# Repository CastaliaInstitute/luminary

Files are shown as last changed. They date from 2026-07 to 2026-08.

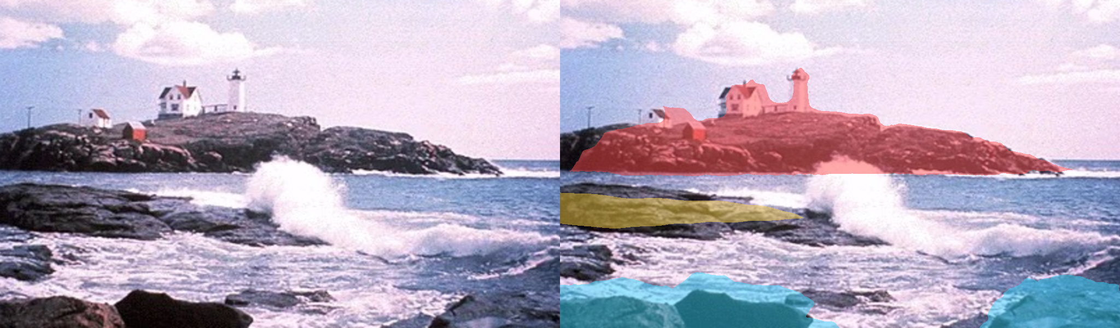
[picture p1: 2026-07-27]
renders/nubble-source-validation.png

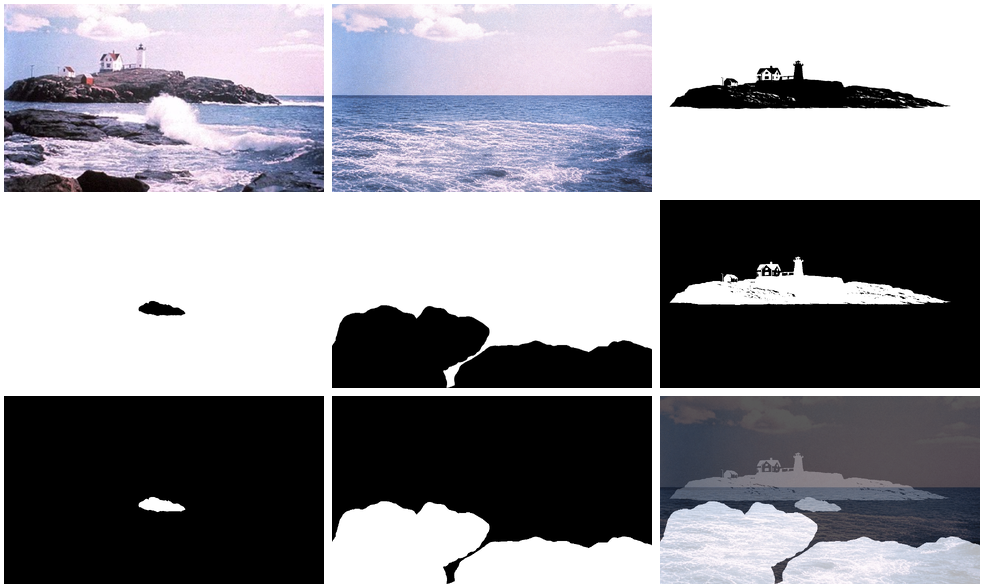
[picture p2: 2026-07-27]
renders/nubble-debug-montage.png

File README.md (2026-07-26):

# Luminary

CastaliaInstitute project repository for **Luminary**, an illuminated coastal shadow box.

## Status

Production-candidate STL package and STL-based render are ready for physical P4 fit testing.
This repository is the source of truth for the Luminary project.

## Repository layout

```text
.
├── README.md
├── blender/        # Blender scene-generation script
├── cad/            # Parametric OpenSCAD model
├── docs/          # Product, design, and technical notes
├── renders/        # Concept render and fit-check STLs
└── src/           # Implementation source
```

## Getting started

The project page is published at [luminary.castalia.institute](https://luminary.castalia.institute).

Open `cad/lightbox.scad` in OpenSCAD to inspect or export the current parametric model.
The latest production-candidate render is `renders/nubble-concept.png`; the editable Blender
scene is `renders/nubble-concept.blend`. The release print set and physical assembly notes are
in [`docs/production-build.md`](docs/production-build.md).

For new scenes, follow the [landscape photo workflow](docs/landscape-photo-workflow.md).
It defines the AI background-fill, source-faithful silhouette, SVG, print-validation, and
off-axis display-alignment process.

The first three-layer example is documented in the [Nubble source run](docs/nubble-source-run.md).
Its exported meshes are in `renders/stl/nubble-*.stl`, with the corresponding actual-STL
Blender render at `renders/nubble-concept.png`.

## Project principles

- Keep the project understandable and easy to pick up.
- Record important product and technical decisions in `docs/`.
- Prefer small, reviewable changes with clear commit messages.

## Maintainer

CastaliaInstitute

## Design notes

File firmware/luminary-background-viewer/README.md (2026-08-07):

# Luminary P4 runtime viewer

Production ESP-IDF firmware for the **Waveshare ESP32-P4-WIFI6-Touch-LCD-7B** only. It drives the 1024×600 EK79007 MIPI-DSI panel in RGB888 and renders a continuously evolving Nubble sea and sky behind the printed bas-relief.

## Registration contract

- Canvas: exactly 1024×600
- Camera bearing: 90°
- Horizon: immutable row **291**
- The packed water mask is false above row 291.
- Cloud opacity is feathered to zero before the horizon and cannot touch the sea.
- Foam can exist only in registered water pixels near the signed shore-distance field.
- Land is physical printed relief; the runtime never invents or moves it.

## Runtime model

The base image is decoded once by the P4 JPEG engine. At 10 fps, firmware then:

1. Projects NDBC's measured swell and wind-wave partitions onto a horizontal world-space sea plane.
2. Animates surface normals and reflections without translating source pixels, then steepens incoming crests into foam only inside the registered shoreline-distance field.
3. Composites GOES high, mid, and low cloud shells, each rotated continuously by its own GOES Derived Motion Wind vector and measured cloud height.
4. Uses the live Nubble camera as the final authority for visible sky color and cloud fraction. A confident clear camera observation sets shell opacity to zero even if an older satellite field contains cloud.
5. Synchronizes UTC directly with SNTP and recalculates York's actual solar altitude and azimuth on the P4 every 30 seconds. Golden hour begins continuously at +10°, peaks at the horizon crossing, and fades through twilight. Sunset remains physically behind the east-facing camera while warming the correctly oriented horizon, clouds, and water reflection. A moon is drawn only when measured altitude/azimuth places it inside the camera view, before cloud compositing so clouds can occlude it.
6. Projects the ESA Hipparcos naked-eye catalogue through the same locked camera. ICRS positions receive catalogue proper motion and date precession before conversion to York-local altitude/azimuth. Solar altitude controls limiting magnitude, and the three measured cloud shells attenuate stars rather than allowing them to shine through cloud.

The compiled asset is an offline-safe fallback. In production the P4 polls a versioned HTTPS manifest every five minutes, downloads changed state, three compact 256×96 luminance/alpha cloud-shell atlases, and a compact 512×300 RGB ocean phase atlas containing up to three independently measured wave components. It verifies every size and CRC32, then activates the complete bundle atomically. It keeps rendering the previous validated bundle through network or upstream failures.

For visual QA on the local network, `GET /runtime/screenshot.ppm` returns a lossless capture of the exact BGR888 scanout framebuffer converted to RGB PPM. This captures only display content; the physical Nubble bas-relief remains intentionally absent.

The default endpoint is the repository's force-refreshed `runtime-live` branch on `raw.githubusercontent.com`, which has a valid public TLS chain. `luminary.castalia.institute` mirrors the project site but is not trusted as a firmware endpoint until its custom-domain certificate is valid.

## Autonomous refresh

The P4 initiates refreshes; it does not require an inbound connection or a Mac on the local network. GitHub Actions preprocesses the heavy NOAA GOES NetCDF products and Nubble live-camera observation into the compact bundle the P4 can consume. The workflow replaces the history-free `runtime-live` branch every five minutes, avoiding unbounded binary Git history.

The scene swap is all-or-nothing:

1. Fetch `manifest.json` over verified HTTPS.
2. Ignore an unchanged `bundle_id`.
3. Download all cache-busted binary assets into temporary PSRAM.
4. Validate byte counts, CRC32 values, state JSON, and immutable horizon row 291.
5. Acquire the renderer lock once and activate the complete bundle.

The cloud and sea fields continue moving from monotonic time while a refresh is downloaded.

## Optional microSD asset cache

Insert a FAT-formatted microSD card in the onboard TF socket to retain the last validated runtime scene across power loss and offline starts. The cache is optional: firmware always boots from its embedded scene when the card is absent, unreadable, or corrupt, and then refreshes over HTTPS when Wi-Fi becomes available.

The P4 stores two alternating files as `/luminary/RUN_A.BIN` and `/luminary/RUN_B.BIN`. Each file contains the state JSON, all three cloud atlases, and the ocean phase field with a sequence number and CRC32. The validity marker is written only after the complete file has been flushed, so a power interruption during an update leaves the other slot intact. At boot, firmware validates both slots and activates the newest complete bundle before connecting to the network. The short filenames remain compatible with builds that omit FAT long-filename support.

The TF socket runs in its board-supported SPI mode on MISO 39, CS 42, CLK 43, and MOSI 44. Firmware enables the board's required on-chip LDO channel 4 before card initialization. This deliberately isolates removable storage from the ESP-C6 Wi-Fi coprocessor, which uses the P4's separate SDIO slot. The fixed Hipparcos catalogue and boot-safe scene remain embedded in flash.

## Maintenance push API

The P4 still listens on port 80 after Wi-Fi connects for development and recovery:

- `POST /runtime/cloud/high`
- `POST /runtime/cloud/mid`
- `POST /runtime/cloud/low`
- `POST /runtime/ocean-phase`
- `POST /runtime/state`

Each cloud payload is exactly 49,152 bytes and the three-component ocean phase payload is exactly 460,800 bytes. The host uploads all binary fields first and the JSON state last; the state request is the visible commit point. The device rejects any state whose horizon is not row 291.

From the repository root:

```sh
python3 scripts/update-york-runtime.py --deploy
```

That command fetches York weather, NDBC 44098 standard and spectral-partition observations, and York tide predictions; observes the live Nubble camera; downloads GOES C13/ACHA clouds and C14 motion winds; builds and validates the cloud and sea fields; packs the runtime assets; then atomically deploys them to the P4. Use `--reuse-dmw` only for offline/repeat testing.

## Optional local builder

The macOS LaunchAgent is an optional development fallback, not part of the production runtime path. It can build and push a scene directly while testing upstream changes. Production data is generated by `.github/workflows/runtime.yml`, and the P4 fetches it itself.

Service label: `institute.castalia.luminary-realtime`

```sh
launchctl print gui/$(id -u)/institute.castalia.luminary-realtime
tail -f ~/Library/Logs/Luminary/realtime.log
```

The host Mac needs to be awake and connected to the P4's local network only when using this optional direct-push path.

Validate and preview without deploying:

```sh
python3 scripts/update-york-runtime.py --reuse-dmw
python3 scripts/preview-p4-runtime.py \
  --state firmware/luminary-background-viewer/assets/v2/nubble-runtime-scene-v1.json \
  --assets firmware/luminary-background-viewer/assets/runtime \
  --output tmp/york-live/runtime-production-preview
python3 scripts/validate-production-runtime.py \
  --state firmware/luminary-background-viewer/assets/v2/nubble-runtime-scene-v1.json \
  --assets firmware/luminary-background-viewer/assets/runtime \
  --preview tmp/york-live/runtime-production-preview
```

## Build and flash

Wi-Fi credentials remain local build inputs in ignored `sdkconfig`; do not put them in source or logs.

```sh
. /Users/danielmcshan/esp/esp-idf-v5.5.1/export.sh
idf.py -B build-runtime set-target esp32p4
idf.py -B build-runtime build
idf.py -B build-runtime -p /dev/cu.wchusbserial5B901846451 flash monitor
```

Only use a serial path after positively identifying this exact P4 board. The current application is about 2.71 MB, leaving roughly 14% of the 3 MB app partition free. The renderer runs on a dedicated task whose stack lives in internal SRAM — a PSRAM or RTC-RAM stack slows every stack access enough to stretch one frame into seconds. The composed sky (clouds, solar grading, moon, stars) is cached in double-buffered PSRAM, rebuilt a few rows per frame when wind or solar state moves it, and blitted only when a framebuffer does not already carry it, so clear and cloudy scenes both hold 10 fps (~96 ms measured under full overcast). Confirm against the serial `runtime cadence` measurements after changing the renderer.

Legacy `.lumv` assets remain under `assets/v2` for comparison, but the production firmware no longer loops finite JPEG sequences.

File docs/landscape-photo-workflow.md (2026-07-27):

# Landscape photo to Luminary bas-relief workflow

The photograph is the composition authority. AI may segment or fill an image,
but it must not redesign the landform, move the horizon, or change the scale
relationship between a distant island, breaker, and foreground rocks.

Luminary's production configuration is a 7 x 5 in landscape shadow box with a
Waveshare ESP32-P4-WIFI6-Touch-LCD-7B at the rear. The physical scene field is
5.5 x 3.5 in (139.7 x 88.9 mm) behind a 5.25 x 3.25 in wood sight aperture.
It uses a 1024 x 600 working canvas. The narrow sight mat deliberately hides
the LCD edge and the cropped field margin.

## 1. Normalize the source

Create `scenes/<scene>/source.png` from the best available photograph:

- landscape orientation;
- exactly 1024 x 600 pixels;
- preserve the intended island, breaker, foreground contours, and horizon;
- do not independently crop later layer inputs.

The source coordinates are geometry. Every generated mask must retain this
same 1024 x 600 canvas and pixel registration.

## 2. Create the land-free LCD background

Use image generation with the source photograph as a reference:

> Edit this supplied landscape photograph into a photorealistic background.
> Preserve its exact horizon height, clouds, atmosphere, water direction, and
> lighting. Remove all land, buildings, shoreline, rocks, foam, and people;
> naturally fill the removed areas with continuous water. Do not move or crop
> the composition, add text, or change the photographic style.

Save the result at `scenes/<scene>/background.png`, exactly 1024 x 600. This
is the only sky and water image displayed by the P4.

## 3. Segment opaque printed layers

Make three source-registered, black-on-white PNG masks, each exactly 1024 x
600, and save them next to the source:

| Layer | File | Physical placement |
| --- | --- | --- |
| Distant island/shore | `island.png` | LCD contact plane |
| Midground peninsula including the breaking-wave rock | `breaker-source-segmentation.png` | 2.5 mm forward |
| Nearest foreground rocks | `foreground.png` | 5.0 mm forward |

The source-derived midground peninsula is intentionally separate from the
distant island and foreground. It must remain connected to its source-side
field edge; do not make its breaker tip into a floating island. Exclude water
and foam. Rocks are opaque; transparent rock areas make the display show
through and invalidate the physical scene.

Use AI only as a segmentation aid. Validate each mask by compositing it over
the original source, at identical pixel dimensions. Reject a mask if it moves
shoreline edges, flattens the bottom profile, makes the foreground too large,
or invents a landform.

White building/lighthouse inserts are optional and must remain out of the print
set until a separately segmented, source-aligned architecture mask is reviewed.
Do not improvise their scale from a generative image.

## 4. Compile and inspect registration

Run:

```sh
scripts/compile-bas-relief.sh <scene>
```

The compiler centre-crops the same 943 x 600 source region from the LCD
background and every mask, then normalizes it back to 1024 x 600 for the
5.5 x 3.5 in physical field. This shared crop is essential: independent
resize/crop steps create visible parallax errors.

Inspect `scenes/<scene>/compiled/reference-alignment.png` before exporting:

- island appears red;
- breaker appears gold;
- foreground appears cyan.

All contours must track the original photograph. This review is against the
source photo, not the generated LCD background.

## 5. Build the printable bas-relief

For Nubble, export the three opaque bases from
`cad/bas_relief_scene.scad`, then create the source-tonal companion meshes:

```sh
python3 scripts/build-rock-texture-mesh.py \
  scenes/<scene>/compiled/island-texture.png \
  renders/stl/<scene>-basrelief-island-texture.stl --base-z 1.6
```

Repeat for breaker (`--base-z 3.2`) and foreground (`--base-z 5.0`). The mesh
samples 0.2 x 0.2 mm XY detail and converts source tones into a maximum 1.35
mm printable height field. Load each texture STL with its matching base STL as
one object in the slicer; print at 0.12 mm layers.

Do not use the 2 in box depth as a 20-35 mm parallax gap. The scene is a
shallow bas-relief: the contact island is at the display, breaker 2.5 mm
forward, and foreground 5 mm forward. That depth is enough to reveal form at
a slight angle while retaining source/background registration.

## 6. Render and verify

Render only imported production STLs:

```sh
LUMINARY_SCENE=nubble /Applications/Blender.app/Contents/MacOS/Blender \
  --background --python blender/luminary_scene.py
scripts/verify-production.sh
```

The verifier rebuilds the source-alignment artifact and checks every required
STL for nonmanifold and boundary edges. Reject the scene if the product render
shows a background shift at the selected three-quarter camera angle, or if the
reference-alignment overlay disagrees with the source photograph.

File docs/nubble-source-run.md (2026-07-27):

# Nubble source run

The Nubble Lighthouse scene is represented by four separate AI-assisted visual assets.
These are the canonical references for the next silhouette revision; do not collapse them
into a generic one-piece trace.

| Layer | Asset | Use |
| --- | --- | --- |
| LCD sky and water | `assets/display-nubble-1280x720.png` | 1280 × 720 display background |
| Distant island and lighthouse | `assets/source/nubble-island-ai.jpg` | Main black island / white-building tracing reference |
| Middle breaker rock | `assets/source/nubble-breaker-rock-ai.png` | Shallow black rock under the crashing wave |
| Foreground boulders | `assets/source/nubble-foreground-rocks-ai.png` | Separate raised black foreground tracing reference |

`assets/source/nubble-background-ai.jpg` is retained as the uncropped background source.

## Layering rule

The island output intentionally contains no foreground boulders. The breaker-rock output
provides the low physical target for the wave. The foreground-rock output intentionally
contains no island, lighthouse, or sky. Keep all three as independent physical layers, held
by the hidden ring and narrow clear traces where a rock is isolated. This preserves open
water on the display between the foreground, breaker, and island.

## Printable extraction

`cad/nubble_layers.scad` turns the approved AI separations into four print-ready meshes:

- `renders/stl/nubble-magnetic-frame.stl` — hidden 6 × 4 in magnetic carrier with four 3.2 mm magnet pockets
- `renders/stl/nubble-island-layer.stl` — distant island and lighthouse mask
- `renders/stl/nubble-breaker-layer.stl` — the single middle rock where the wave breaks
- `renders/stl/nubble-foreground-layer.stl` — near boulders

The first is installed behind the wood mat; the three opaque masks stack toward the glass.
The LCD remains the fourth visual layer (sky and water), mounted at the rear of the fixed
2 in box. Artwork is registered for the straight-on viewing position; the angled view is
allowed to reveal the intended shadow-box parallax.
`renders/nubble-concept.png` is the Blender render made by importing those exact STL files.

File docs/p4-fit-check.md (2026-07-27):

# Luminary P4 physical fit check

Run this check before printing or installing the structural rear plate. It
validates the specific Waveshare ESP32-P4-WIFI6-Touch-LCD-7B board used by
Luminary; do not substitute the earlier portrait 5-inch P4 board.

## Evidence used by the CAD

The Waveshare outline drawing specifies a 164.00 x 97.00 mm board and a
164.28 x 99.17 mm LCD/bezel envelope. The rear plate's 166.0 x 101.6 mm
registration land therefore leaves 0.86 mm clearance at each long side and
1.215 mm at each short side of the bezel. The low-material fit ring uses the
same nominal corner-hole centers as the rear plate: +/-78 mm X and +/-44 mm Y,
with 6.0 x 5.2 mm horizontal M2.5 tolerance slots.

Source: [Waveshare ESP32-P4-WIFI6-Touch-LCD-7B outline drawing](https://www.waveshare.com/esp32-p4-wifi6-touch-lcd-7b.htm).

## Print

Print [luminary-7in-p4-fit-check.stl](../renders/stl/luminary-7in-p4-fit-check.stl)
flat in the intended rear-plate material at 0.20 mm layers. It is deliberately
only 1 mm thick and consumes little material. Do not scale it.

## Acceptance criteria

1. The board perimeter must sit entirely inside the 166.0 x 101.6 mm ring
   without forcing or bowing the printed plastic.
2. Each of the four board mounting holes must accept an M2.5 screw through its
   corresponding test-ring slot with at least 0.5 mm of unforced adjustment in
   both axes.
3. With all four screws finger-tightened, the LCD/bezel must lie flat and
   centered; no corner may lift more than 0.3 mm from the registration land.
4. Connect the selected right-side USB-C extension internally and route its
   external cable through both the side and bottom-center 8 mm plate exits.
   The connector and cable must not bear against the PCB, display flex, or
   screw head.
5. Confirm the selected 6 x 2 mm magnets sit below the rear plate surface and
   that their polarity attracts the intended steel-frame plates.

If any criterion fails, measure the actual board-hole coordinates from the
board center, edit the constants at the top of
`cad/luminary-7in-backplate.scad` and
`cad/luminary-7in-p4-fit-check.scad` together, then re-export both STLs.
Never enlarge a completed structural plate by drilling; that can reduce the
wall around its cable exits or magnet pockets.

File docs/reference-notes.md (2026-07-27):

# Lightbox CAD reference notes

## Source references

- `references/Living_Landscape_Shadow_Box_Design_v0.1.pdf`
- `references/Photo 1.jpg`
- `references/Photo 2.jpg`
- `references/Pasted Image 1.jpg`
- `references/Distressed White Frame.jpg`
- `assets/living-landscape-silhouette.svg`
- `assets/living-landscape-foreground.svg`
- `assets/living-landscape-structures.svg`

## Dimensions captured

| Feature | Value | Confidence |
| --- | ---: | --- |
| Nominal shadow-box exterior | 7 × 5 × 2 in (177.8 × 127.0 × 50.8 mm) | Design brief + measured depth |
| Nominal interior / silhouette panel | 6 × 4 in (152.4 × 101.6 mm) | Design brief |
| Waveshare display outer envelope | 126.90 × 70.70 mm | Product reference image |
| Display active area | 110.32 × 62.28 mm | Product reference image |
| Waveshare PCB envelope | 118.50 × 64.50 mm | Product reference image |
| Silhouette mounting frame | 4 × 6 in, 0.8 mm face, hidden under 8 mm glass rabbet | Design brief + mechanical revision |
| Inner mounting-frame edge | 2 mm tapered feather | Mechanical revision |
| Hidden rear ribs | ~2 mm deep | Design brief |
| Magnet reference | 3 × 1 mm neodymium | Design brief |
| Silhouette-to-display depth | 20 mm target | Reduces off-axis parallax while retaining shadow depth |
| Clear glass / mat opening | 114.3 × 88.9 mm (4.5 × 3.5 in) | Actual visible front aperture |
| Printed rear plate | 177.8 × 127.0 mm (5 × 7 in) | New mechanical requirement |
| Shallow rear registration land | 152.4 × 101.6 mm (4 × 6 in) | New mechanical requirement |
| USB-C cable pass-throughs | 8 mm circular default, side + bottom-center | New mechanical requirement |
| Silhouette magnet reference | 3 × 1 mm magnet in 8 × 8 × 2 mm hidden corner pod, 4 corners | Design brief + mechanical revision |
| Glass steel squares | 1/4 × 1/4 in, 4 corners | New mechanical requirement |

## Modeling assumptions

The OpenSCAD model is a fit-check starter, not a release-ready manufacturing model. The
following need physical verification before printing a final carrier or enclosure:

- actual frame inner opening, rabbet, glass thickness, and usable depth;
- display-to-frame registration and cable exit locations;
- PCB mounting-hole coordinates and connector keep-outs;
- magnet polarity, steel-square placement, and pocket tolerances;
- whether the 4 × 6 panel is centered or offset within the frame.
- exact cable diameter, grommet choice, and cable bend radius;
- exact P4 PCB hole coordinates and connector keep-outs;
- steel plate thickness, position, and spacing relative to the silhouette magnet pockets.

The 2 in outer depth is now the controlling dimension. The model uses a 20 mm
silhouette-to-screen depth, preserving roughly 30 mm for the display carrier, P4 PCB,
rear plate, and clearance. This reduces the background's apparent shift when viewed at a
slight angle. This is a fit allocation, not proof of fit; confirm the tallest P4-side
component before printing.

## Usage

Open `cad/lightbox.scad` in OpenSCAD and set `part` to `assembly`, `silhouette`, `structures`,
`glass_hardware`, `backplate`, `carrier`, `display`, or `pcb`. Render with F6, then export the selected part as STL. The geometry is
centered on the origin so it can be aligned with a future SVG-derived landscape silhouette.

## Silhouette composition

`assets/lighthouse-silhouette-source-v3.png` is the latest AI-assisted, source-preserving
tracing reference. `assets/living-landscape-photo-trace.svg` is its Potrace-derived black
relief used by the CAD: compact island, separated foreground boulders, and modest lighthouse
scale rather than the earlier abstract trace. Sky, water, and surf are intentionally omitted
so the display can provide those elements and their animation.

## Relief strategy

The silhouette is designed around a 0.2 mm nozzle: the source-traced black scene is 4 layers
(0.8 mm) and bonds to the transparent carrier. The lighthouse and cottage insert is a
separate white-print part at 6 layers (1.2 mm). The lantern center is intentionally open,
allowing the display image to show through it.

## Render handoff

The Blender scene generator is `blender/luminary_scene.py`. From the repository root:

```sh
/Applications/Blender.app/Contents/MacOS/Blender --background --python blender/luminary_scene.py
```

This writes the editable scene and the current concept render to `renders/`. The render omits
the real glass door so the display and relief remain legible; the physical assembly still
reserves the glass-door layer.

Current fit-check exports:

- `renders/stl/luminary-backplate.stl` — printed 5 × 7 rear plate
- `renders/stl/luminary-display-carrier.stl` — P4 display carrier
- `renders/stl/luminary-silhouette-carrier.stl` — clear hidden ring, magnet pods, and support traces
- `renders/stl/luminary-silhouette.stl` — black source-derived island and foreground rocks
- `renders/stl/luminary-structures.stl` — white lighthouse and building insert
- `renders/stl/p4-reference-model.stl` — simplified, dimensioned P4 display/PCB fit-check model
- `renders/stl/p4-5_5x3_5-aspect-mask.stl` — two thin black LCD-mask rails, reducing the visible scene to 97.83 × 62.28 mm

All five were exported from `cad/lightbox.scad` with OpenSCAD and checked as non-empty
ASCII STL meshes. The silhouette carrier is deliberately a ring-and-trace design; it is
not a full clear 4 × 6 panel.
- `renders/luminary-display.stl`

## Rear plate architecture

The rear of the object is a **matte-black PLA printed 5 × 7 plate**, not a separate wood
backing. A shallow 4 × 6 registration land provides the mounting datum for the P4/display
assembly at the rear of the 2 in box. Four rear-facing pockets accept magnets that
mate with steel plates bonded to the inside back of the shadow-box frame. The default USB-C
access is provided by two small circular pass-throughs in the printed back: one on the side
for wall mounting and one centered along the bottom for tabletop placement. The connector
stays internal and the cable routes through the selected hole. Diameter and edge offsets are
parameterized for the actual cable or grommet.

The removable silhouette is retained separately by four 3 × 1 mm magnets in its corner
pockets. Its clear carrier is a 0.4 mm (two-layer, 0.2 mm nozzle) perimeter ring hidden
under the 8 mm glass-mounting rabbet, plus two 0.6 mm clear support traces behind isolated
foreground boulders—not a full 4 × 6 sheet. The source-traced island reaches the side
margins directly. Clear PLA is acceptable for these traces; clear PETG generally finishes
more transparent. Each magnet aligns to a 1/4 × 1/4 inch steel square bonded to the inside face of
the glass door. `glass_hardware` renders those steel squares as a fit-check overlay; verify
final adhesive thickness and corner offsets on the actual glass before printing.

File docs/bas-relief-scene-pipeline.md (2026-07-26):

# Bas-relief scene pipeline

Luminary scenes are compiled from an image set, not manually redrawn. The output is a
source-faithful 2.5D relief in front of a full-screen P4 background.

## Inputs per scene

```text
scenes/<name>/source.png          # original reference, 1024 x 600 master canvas
scenes/<name>/background.png      # same canvas, land/foreground removed
scenes/<name>/island.png          # distant island/lighthouse opaque mask
scenes/<name>/breaker.png         # middle breaking-wave rock opaque mask
scenes/<name>/foreground.png      # nearest rocks opaque mask
```

Every input must share pixel coordinates and be exactly 1024 x 600. AI is used only to make `background.png`
and the source-aligned masks; the deterministic compiler produces `depth.png`. Their outputs are reviewed over the source before
compilation. Do not let a 3D generator invent coastline geometry.

## Deterministic compile

1. Validate every input is 1024 x 600 (the confirmed 7 in P4 panel resolution).
2. Threshold/trace opaque masks into SVG outlines.
3. Generate a review depth map: island 1.6 mm, breaker 3.2 mm, foreground 5.0 mm.
4. Preserve image-space coordinates exactly; do not trim, crop, or recenter a layer.
5. Generate separate STLs: dark relief layers and a white architecture insert.
6. Render against the 1024 x 600 P4 background and inspect at straight-on plus
   a 5–8 degree off-axis angle.

## Design limits

- Keep total relief depth at or below 8 mm.
- Distant land: 0.8–2 mm; foreground: 3–5 mm; reserve 5–8 mm for only the nearest rocks.
- The P4 stays at the rear of the 2 in box; parallax comes from relief depth, not moving
  or cropping the display.
- A lighthouse is a source-matched tapered bas-relief with a small clear lantern inset,
  never a generic freestanding object.

## Human checkpoint

Before STL export, overlay each mask and depth band at 50% opacity on `source.png`.
Approve shoreline, lighthouse, breaker, and foreground alignment. This one review step is
what keeps scenes recognizable across different photographs.

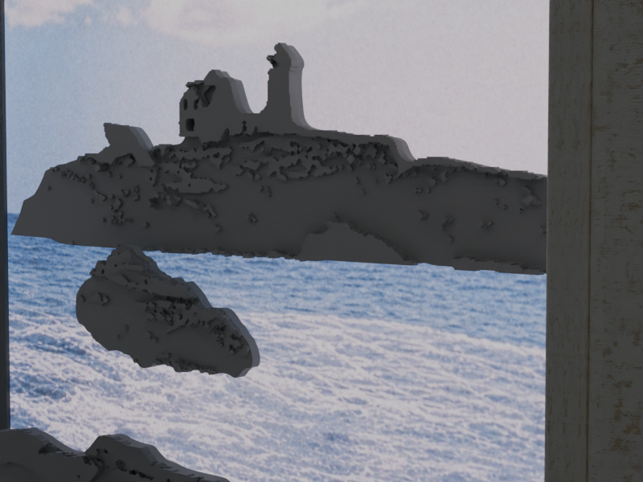
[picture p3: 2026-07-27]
renders/nubble-concept-rock-texture-detail.png

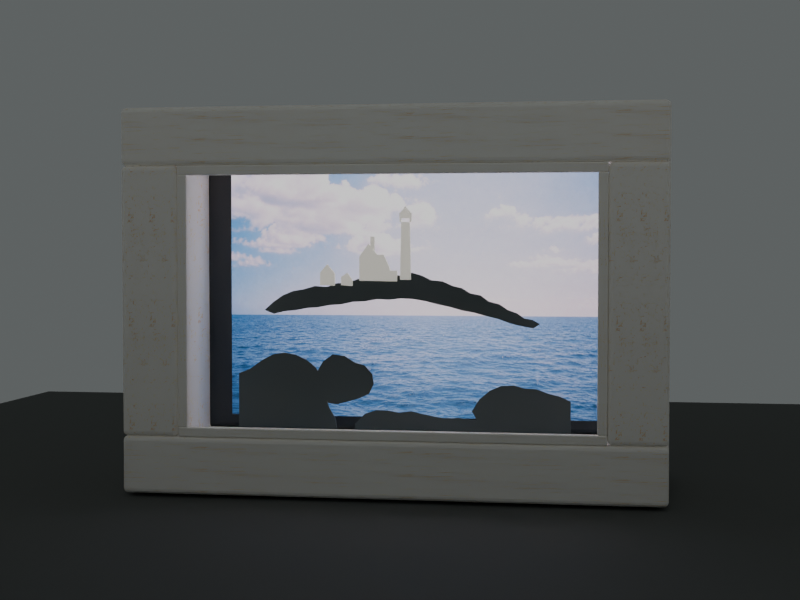
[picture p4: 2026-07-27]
renders/luminary-concept.png

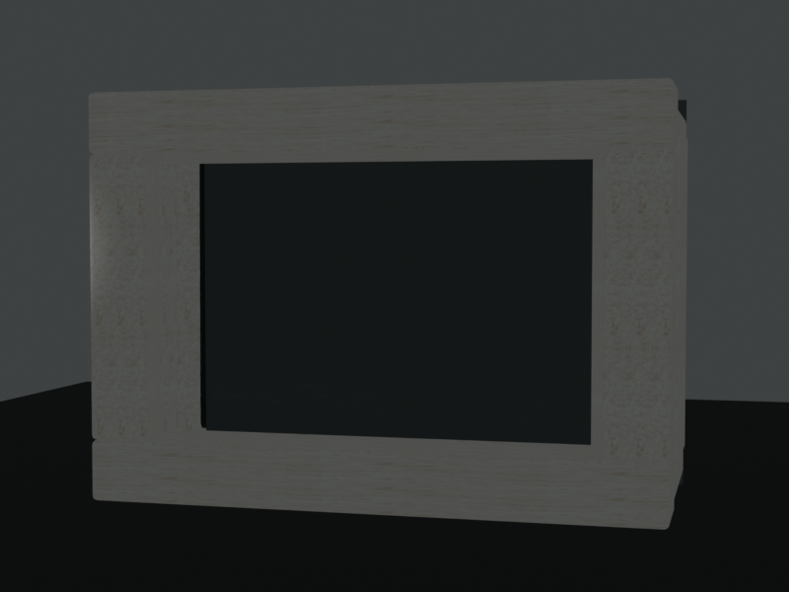
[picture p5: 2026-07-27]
renders/nubble-concept.png

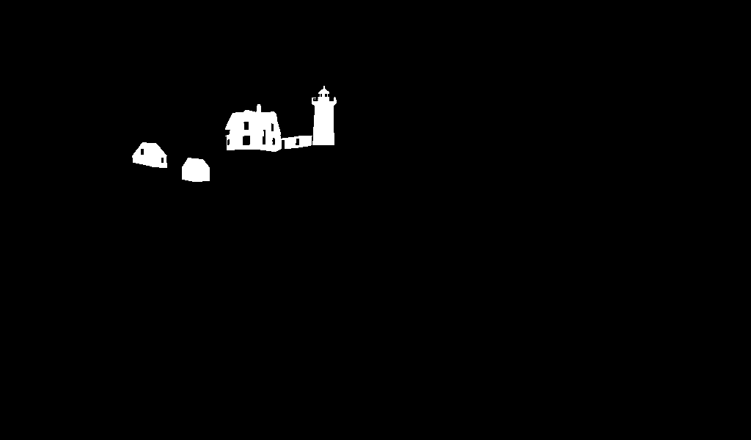
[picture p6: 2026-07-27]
scenes/nubble-aligned/architecture-ai-v1-1024x600.png

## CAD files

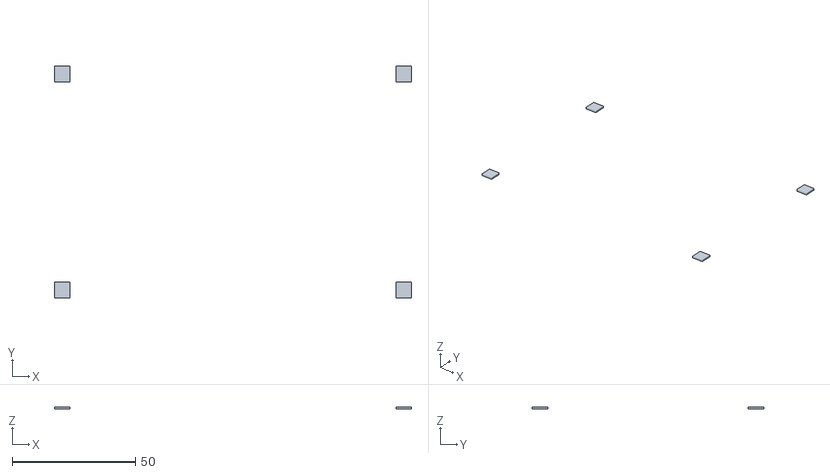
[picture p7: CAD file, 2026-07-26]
renders/luminary-glass-hardware.stl
144.8 x 93.9 x 1.00

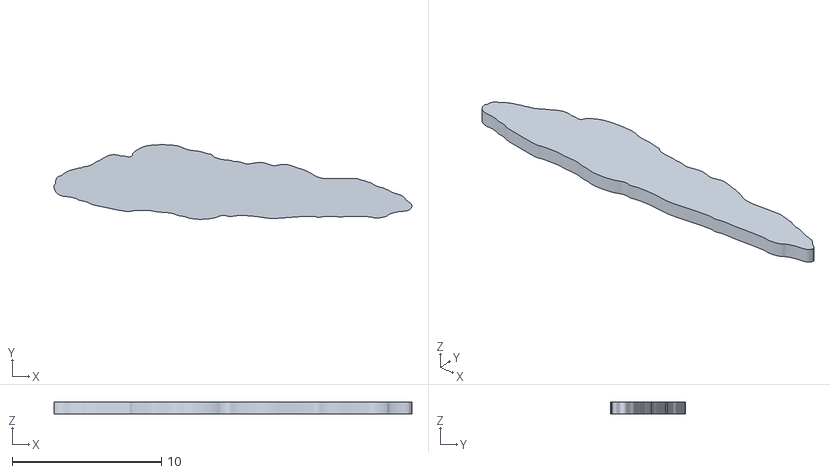
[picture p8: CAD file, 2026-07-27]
renders/stl/nubble-breaker-layer.stl
24.0 x 5.00 x 0.8

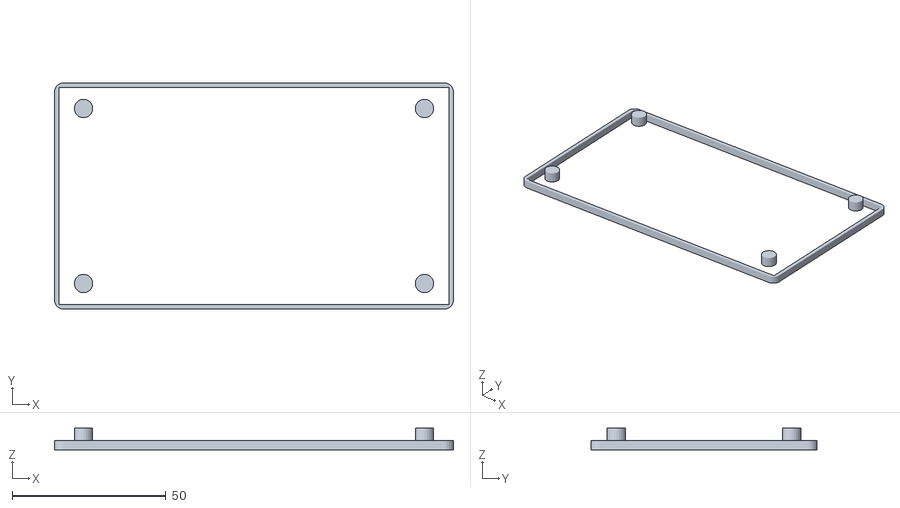
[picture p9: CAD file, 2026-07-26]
renders/luminary-carrier.stl
129.9 x 73.7 x 7.00

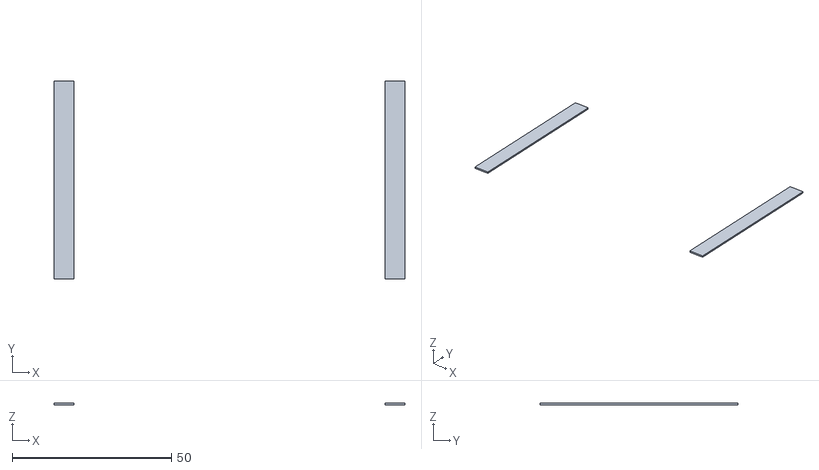
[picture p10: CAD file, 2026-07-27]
renders/stl/p4-5_5x3_5-aspect-mask.stl
110.3 x 62.3 x 0.6

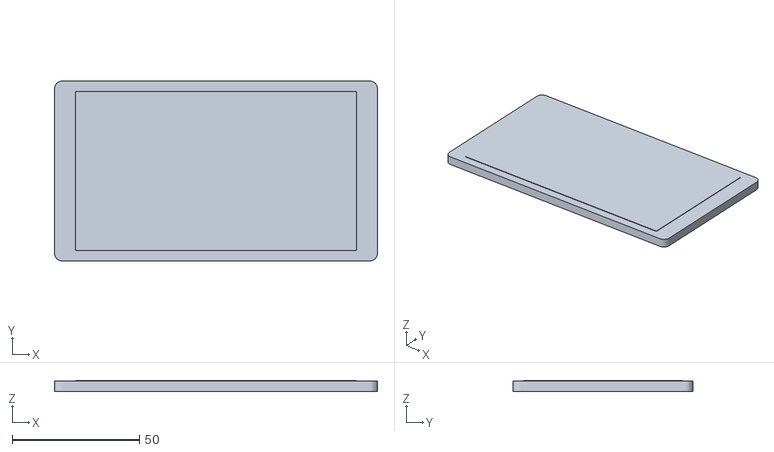
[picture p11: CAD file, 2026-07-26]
renders/luminary-display.stl
126.9 x 70.7 x 4.20

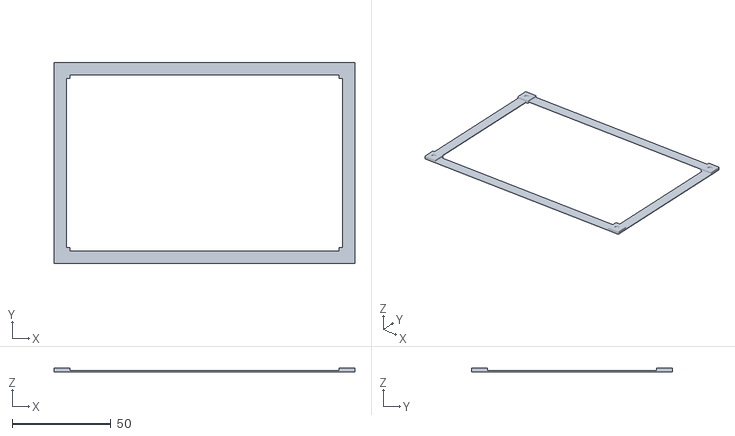
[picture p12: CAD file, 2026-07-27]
renders/stl/nubble-magnetic-frame.stl
152.4 x 101.6 x 2.00

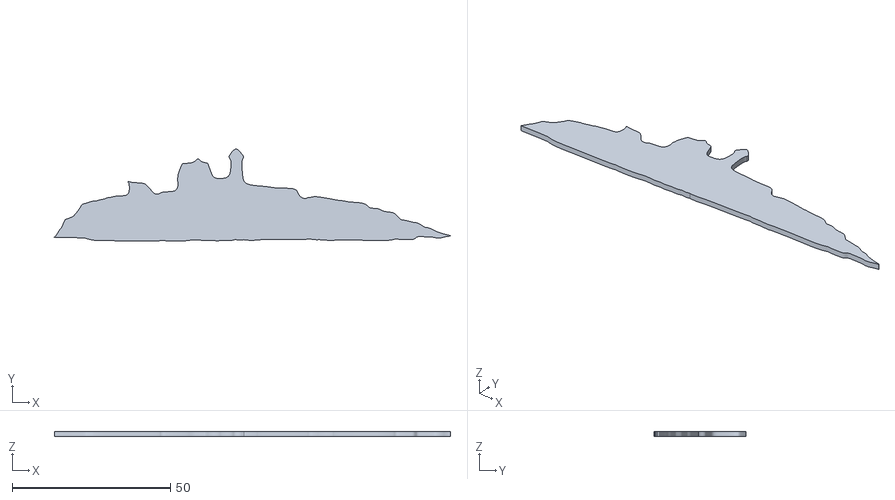
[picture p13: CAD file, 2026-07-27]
renders/stl/nubble-basrelief-island.stl
125.3 x 29.2 x 1.60

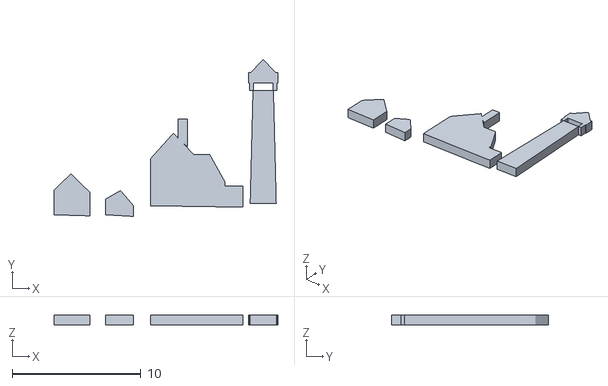
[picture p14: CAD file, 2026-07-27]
renders/stl/nubble-basrelief-architecture.stl
17.4 x 12.2 x 0.8

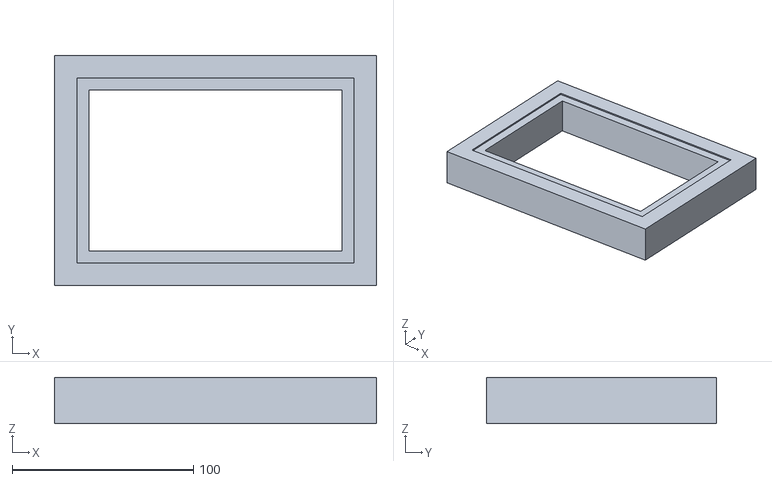
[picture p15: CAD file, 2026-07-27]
renders/stl/luminary-front-door-reference.stl
177.8 x 127.0 x 25.4

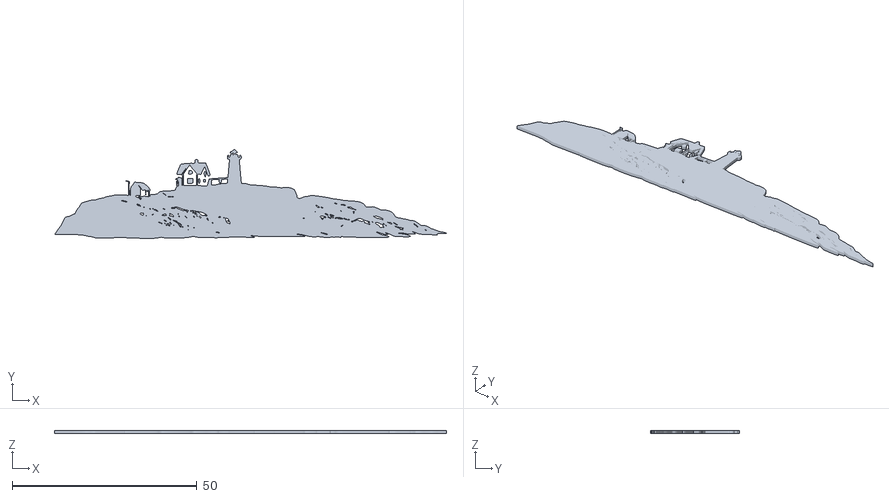
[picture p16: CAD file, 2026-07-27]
renders/stl/nubble-island-layer.stl
106.0 x 24.0 x 0.8

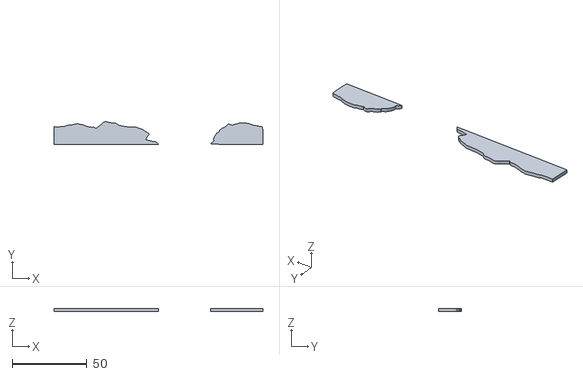
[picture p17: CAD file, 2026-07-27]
renders/stl/nubble-basrelief-foreground.stl
139.7 x 15.1 x 1.80

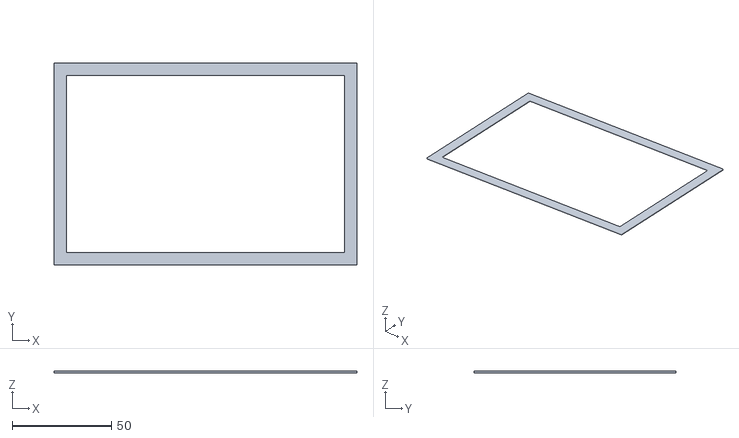
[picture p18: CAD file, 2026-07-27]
renders/stl/nubble-display-contact-frame.stl
152.4 x 101.6 x 0.8

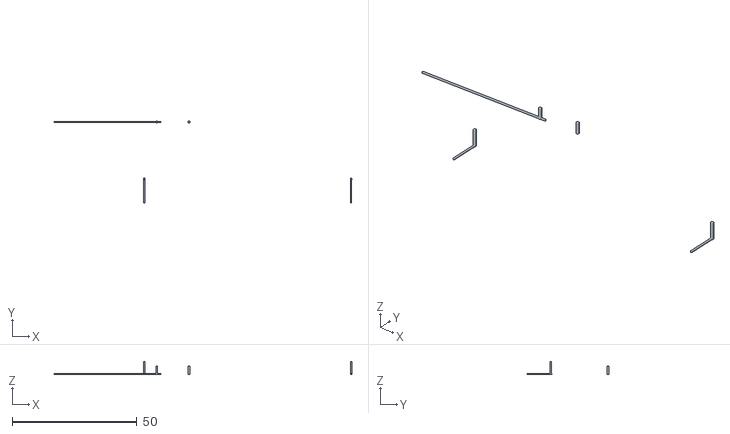
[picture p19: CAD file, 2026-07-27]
renders/stl/nubble-clear-supports.stl
119.6 x 32.8 x 5.35

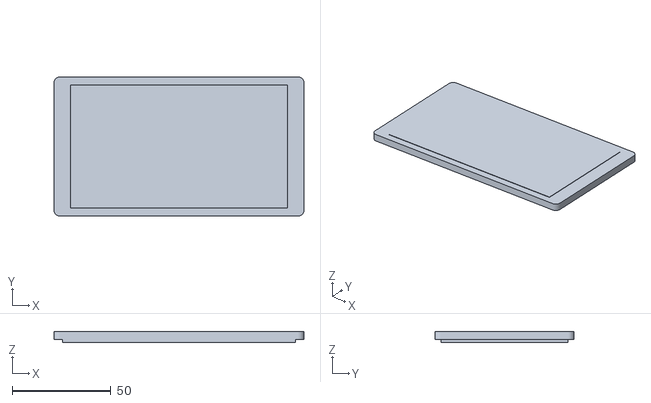
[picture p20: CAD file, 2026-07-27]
renders/stl/p4-reference-model.stl
126.9 x 70.7 x 5.80

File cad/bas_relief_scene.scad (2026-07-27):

// Generic Luminary source-faithful bas-relief compiler.
// Supply a compiled scene directory created by scripts/compile-bas-relief.sh.

$fn = 48;
scene = "nubble-aligned";
part = "assembly"; // island, island_texture, architecture, breaker, breaker_texture, foreground, foreground_texture, assembly
scene_w = 139.7; // 5.5 in visible opening
scene_h = 88.9;  // 3.5 in visible opening
// OpenSCAD imports SVG `pt` units as 0.3527778 mm. Preserve canvas positions
// by converting that unit explicitly rather than resizing each layer's bounds.
svg_pt_mm = 0.3527778;
texture_depth = 0.75; // mm, source-derived rock detail above each base layer
texture_enabled = true; // set false for fast silhouette-only validation exports

module layer(name, depth) {
    translate([-scene_w / 2, -scene_h / 2, 0])
        scale([scene_w / (1024 * svg_pt_mm), scene_h / (600 * svg_pt_mm), 1])
            linear_extrude(height = depth)
                import(str("../scenes/", scene, "/compiled/", name, ".svg"));
}

// The compiler turns the masked photograph into three nested vector texture
// bands. This retains printable rock character without the huge, fragile STL
// created by a per-pixel terrain mesh.
module rock_texture(name, z, depth = texture_depth) {
    for (band = [[45, depth * 0.34], [65, depth * 0.67], [82, depth]])
        translate([-scene_w / 2, -scene_h / 2, z])
            scale([scene_w / (700 * svg_pt_mm), scene_h / (444 * svg_pt_mm), 1])
                linear_extrude(height = band[1])
                    import(str("../scenes/", scene, "/compiled/", name,
                               "-texture-", band[0], ".svg"));
}

module textured_layer(name, z, depth) {
    translate([0, 0, z]) layer(name, depth);
    if (texture_enabled) rock_texture(name, z + depth);
}

// Image-space masks are mounted inside a 5.5 x 3.5 in visible field. These
// depths provide parallax without turning the scene into a diorama.
module island() { textured_layer("island", 0, 1.6); }
// White architectural insert derived from the Nubble lighthouse tracing. The
// lantern centre remains open so the LCD supplies the transparent glazing.
module architecture() {
    // Kept deliberately smaller than the island mass: it overlays the traced
    // building footprints rather than becoming a freestanding 3D lighthouse.
    translate([-39.9, -17.5, 1.65])
        scale([0.45 * scene_w / 142.4, 0.45 * scene_h / 91.6, 1])
            linear_extrude(height = 0.8)
                import("../assets/living-landscape-structures.svg");
}
module breaker() { textured_layer("breaker", 1.6, 1.6); }
module foreground() { textured_layer("foreground", 3.2, 1.8); }
module island_texture() { rock_texture("island", 1.6); }
module breaker_texture() { rock_texture("breaker", 3.2); }
module foreground_texture() { rock_texture("foreground", 5.0); }

if (part == "island") island();
if (part == "island_texture") island_texture();
if (part == "architecture") architecture();
if (part == "breaker") breaker();
if (part == "breaker_texture") breaker_texture();
if (part == "foreground") foreground();
if (part == "foreground_texture") foreground_texture();
if (part == "assembly") { island(); breaker(); foreground(); }

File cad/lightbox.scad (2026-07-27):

// Luminary / Living Landscape shadow-box model
// Units: millimetres. Reference: docs/reference-notes.md
//
// Render one part at a time by changing `part` below:
//   "assembly", "preview", "silhouette", "silhouette_carrier", "structures", "glass_hardware", "backplate", "carrier", "display", "pcb", "p4", "p4_mask"

$fn = 64;

part = "assembly";

// Shadow-box envelope
frame_outer_w = 177.8; // 7 in landscape door
frame_outer_h = 127.0; // 5 in landscape door
shadow_box_depth = 50.8; // 2 in overall depth
scene_frame_w = 152.4; // 6 in hidden magnetic scene insert
scene_frame_h = 101.6; // 4 in hidden magnetic scene insert
p4_mount_w = 166.0;    // board is 164 mm wide; 1 mm relief each side
p4_mount_h = 101.6;
glass_visible_w = 139.7; // 5.5 in clear door window
glass_visible_h = 88.9;  // 3.5 in clear door window

// Waveshare ESP32-P4-WiFi6-Touch-LCD-7 reference dimensions (supplied 7 in outline).
display_w = 164.28;
display_h = 99.17;
active_w = 154.58;
active_h = 86.42;
pcb_w = 164.00;
pcb_h = 97.00;

// Printed rear plate / mounting architecture. Print in matte black PLA; this
// is the structural P4 mounting plate, not a separate wood-frame backing.
backplate_t = 3.0;
insert_t = 1.0; // shallow registration land; keeps the display close to the frame back
insert_border = 5.0;
rear_wall = 2.5;
rear_magnet_d = 3.2;
rear_magnet_h = 1.2;
rear_magnet_edge = 9.0;
usb_side = "left"; // "left" or "right"
usb_cable_cutout_d = 8.0; // small circular cable pass-through
usb_cutout_y = 0.0;
usb_edge_clearance = 3.0;
usb_bottom_edge_clearance = 3.0;

// Printed silhouette panel
silhouette_t = 0.80;
silhouette_carrier_t = 0.40; // two 0.20 mm clear-filament layers behind all art
glass_rabbet_margin = 8.0; // hidden by the door's glass-mounting margin
panel_border = glass_rabbet_margin;
tapered_edge_w = 2.0; // final portion of mount frame feathered toward clear window
scene_art = true;
nozzle_d = 0.20;
scene_base_layers = 4;       // 0.80 mm: visible face
scene_mid_layers = 6;        // 1.20 mm: white architecture and middle shoreline
scene_foreground_layers = 8; // 1.60 mm: dark foreground rocks
rib_t = 2.0;
rib_h = 6.0;
magnet_d = 3.0;
magnet_h = 1.0;
magnet_edge = 4.0; // centers each 8 mm pod within the hidden perimeter
magnet_pod_w = 8.0;
magnet_pod_t = 2.0; // hidden depth; gives the 1 mm magnet a real pocket
svg_field_w = 142.4;
svg_field_h = 91.6;

// Glass-door attachment hardware
steel_square_w = 6.35; // 1/4 in
steel_square_t = 1.0;
steel_square_edge = 4.0;
show_glass_hardware = true;

// Carrier and stack-up assumptions; verify against the actual frame.
carrier_t = 3.0;
carrier_clearance = 1.5;
// The P4 sits directly against the rear mounting architecture. The full box
// depth is available for the layered relief, as it should be in a shadow box.
display_gap = 35.0;
pcb_standoff_h = 2.5;

module rounded_box(size, radius = 3) {
    hull() {
        for (x = [radius, size[0] - radius])
            for (y = [radius, size[1] - radius])
                translate([x, y, 0]) cylinder(r = radius, h = size[2]);
    }
}

module magnet_pocket(x, y) {
    // Pocket opens on the rear of the hidden corner pod. A 0.8 mm face remains
    // between magnet and glass, while the magnet stays invisible from the front.
    translate([x, y, magnet_pod_t - magnet_h - 0.01])
        cylinder(d = magnet_d + 0.20, h = magnet_h + 0.02);
}

module corner_magnet_pod(x, y) {
    difference() {
        // Overlap the carrier by 0.10 mm; coplanar contact is not a printable union.
        translate([x - magnet_pod_w / 2, y - magnet_pod_w / 2, silhouette_carrier_t - 0.10])
            cube([magnet_pod_w, magnet_pod_w, magnet_pod_t - silhouette_carrier_t + 0.10]);
        magnet_pocket(x, y);
    }
}

module frame_ring_2d(outer_w, outer_h, inner_w, inner_h) {
    difference() {
        square([outer_w, outer_h], center = true);
        square([inner_w, inner_h], center = true);
    }
}

module tapered_mount_frame(height = silhouette_t) {
    // Rigid outer portion: hidden beneath the door rabbet and strong enough to
    // carry the corner pods.
    linear_extrude(height = height)
        frame_ring_2d(scene_frame_w, scene_frame_h,
                      scene_frame_w - 2 * (panel_border - tapered_edge_w),
                      scene_frame_h - 2 * (panel_border - tapered_edge_w));

    // The final 2 mm toward the clear window feathers away instead of creating
    // a hard visible frame edge.
    linear_extrude(height = height, scale = 0.94)
        frame_ring_2d(scene_frame_w - 2 * (panel_border - tapered_edge_w),
                      scene_frame_h - 2 * (panel_border - tapered_edge_w),
                      scene_frame_w - 2 * panel_border,
                      scene_frame_h - 2 * panel_border);
}

module glass_steel_square(x, y) {
    // Square is bonded to the inside face of the glass; the magnet is retained
    // in the silhouette panel directly behind it.
    translate([x, y, -steel_square_t])
        cube([steel_square_w, steel_square_w, steel_square_t], center = true);
}

module glass_hardware() {
    for (x = [-scene_frame_w / 2 + steel_square_edge, scene_frame_w / 2 - steel_square_edge])
        for (y = [-scene_frame_h / 2 + steel_square_edge, scene_frame_h / 2 - steel_square_edge])
            glass_steel_square(x, y);
}

module transparent_silhouette_carrier() {
    // Clear carrier is deliberately only a hidden rabbet ring—not a full 4x6
    // sheet. The photograph-derived island reaches the side margins itself.
    union() {
        // A simple closed ring is more reliable than the former coplanar taper.
        linear_extrude(height = silhouette_carrier_t)
            frame_ring_2d(scene_frame_w, scene_frame_h,
                          scene_frame_w - 2 * panel_border,
                          scene_frame_h - 2 * panel_border);

        // Two hairline supports retain otherwise isolated foreground boulders.
        // They terminate under dark rock and remain visually absent over water.
        for (x = [-10, 34])
            linear_extrude(height = silhouette_carrier_t)
                hull() {
                    translate([x, -scene_frame_h / 2 + panel_border + 0.2]) circle(d = 0.6);
                translate([x, -23]) circle(d = 0.6);
            }

        // Island no longer stretches across the opening. These two short clear
        // ties terminate behind its left/right rock shelf and disappear into
        // the rabbet ring.
        for (side = [-1, 1])
            linear_extrude(height = silhouette_carrier_t)
                hull() {
                    translate([side * (scene_frame_w / 2 - panel_border + 1.0), 7]) circle(d = 0.6);
                    translate([side * 47.5, 7]) circle(d = 0.6);
                }

        // Four hidden rear pods carry the magnets that couple to the steel squares.
        for (x = [-scene_frame_w / 2 + magnet_edge, scene_frame_w / 2 - magnet_edge])
            for (y = [-scene_frame_h / 2 + magnet_edge, scene_frame_h / 2 - magnet_edge])
                corner_magnet_pod(x, y);
    }
}

module dark_silhouette_panel() {
    // Source-traced island and foreground boulders, bonded to the transparent
    // carrier rather than forced to grow visible side bridges.
    if (scene_art)
        translate([-glass_visible_w / 2, -glass_visible_h / 2, silhouette_carrier_t])
            scale([glass_visible_w / svg_field_w,
                   glass_visible_h / svg_field_h, 1])
                linear_extrude(height = nozzle_d * scene_base_layers)
                    import("../assets/living-landscape-photo-trace.svg");

}

module white_structures() {
    // Print separately in white. The two narrow lantern mullions in the SVG
    // leave its centre open; that transparent window is lit by the display.
    translate([-glass_visible_w / 2, -glass_visible_h / 2, silhouette_carrier_t])
        scale([glass_visible_w / svg_field_w,
               glass_visible_h / svg_field_h, 1])
            linear_extrude(height = nozzle_d * scene_mid_layers)
                import("../assets/living-landscape-structures.svg");
}

module rear_magnet_pocket(x, y) {
    // Pockets open on the rear face toward the steel plates in the frame.
    translate([x, y, -0.01])
        cylinder(d = rear_magnet_d + 0.25, h = rear_magnet_h + 0.02);
}

module p4_mount_slot(x, y) {
    // 5 x 3.2 mm tolerance slot for M2.5 hardware. It tolerates small
    // differences between the reference drawing and the actual board holes.
    translate([x - 2.5, y - 1.6, -0.01]) cube([5.0, 3.2, backplate_t + 0.02]);
}
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

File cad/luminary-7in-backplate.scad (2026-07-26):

// Luminary 7-inch P4 rear mounting plate — production export.
// Matte-black PLA; dimensions in millimetres. Export directly to STL.
//
// Confirmed P4 envelope: PCB 164 x 97 mm; LCD/bezel 164.28 x 99.17 mm.
// The mounting pattern uses 6 x 5.2 mm tolerance slots for M2.5 fasteners
// because the vendor image does not certify exact hole-center coordinates.

$fn = 20;

plate_w = 177.8;  // 7 in
plate_h = 127.0;  // 5 in
plate_t = 3.0;

p4_land_w = 166.0;
p4_land_h = 101.6;
p4_land_t = 1.2;

slot_dx = 78.0;
slot_dy = 44.0;
slot_len = 6.0;
slot_d = 5.2;
counterbore_d = 5.8;
counterbore_t = 1.4;

magnet_d = 6.2;       // 6 mm nominal disc magnet clearance
magnet_t = 2.1;       // 2 mm nominal disc magnet clearance
magnet_dx = plate_w / 2 - 9.0;
magnet_dy = plate_h / 2 - 9.0;

cable_d = 8.0;
// Keep each exit fully circular with a 1 mm structural wall at the plate edge.
// The USB-C extension is connected internally; these holes only pass the cable.
cable_edge_wall = 1.0;
cable_edge_offset = cable_d / 2 + cable_edge_wall;

module rounded_plate() {
    // The wood shadow box hides the plate perimeter, so a plain rectangular
    // envelope is both stronger and much faster to compile than cosmetic
    // corner fillets.
    translate([-plate_w / 2, -plate_h / 2, 0]) cube([plate_w, plate_h, plate_t]);
}

module pill_slot(length, diameter) {
    hull() {
        translate([-(length - diameter) / 2, 0]) circle(d = diameter);
        translate([(length - diameter) / 2, 0]) circle(d = diameter);
    }
}

module p4_fastener(x, y) {
    translate([x, y, -0.01]) linear_extrude(height = plate_t + 0.02)
        pill_slot(slot_len, slot_d);
    // Recess the screw head on the rear face so it does not stand off from the
    // wooden frame or its steel attachment squares.
    translate([x, y, -0.01]) cylinder(d = counterbore_d, h = counterbore_t + 0.02);
}

module backplate() {
    difference() {
        union() {
            rounded_plate();
            translate([-p4_land_w / 2, -p4_land_h / 2, plate_t - 0.01])
                cube([p4_land_w, p4_land_h, p4_land_t]);
        }
        for (x = [-slot_dx, slot_dx])
            for (y = [-slot_dy, slot_dy]) p4_fastener(x, y);

        // Four rear-facing pockets accept magnets that couple to steel squares
        // fixed inside the shadow-box frame.
        for (x = [-magnet_dx, magnet_dx])
            for (y = [-magnet_dy, magnet_dy])
                translate([x, y, -0.01]) cylinder(d = magnet_d, h = magnet_t + 0.02);

        // Either cable route can be used: side for a wall install, bottom for
        // a tabletop orientation. The unused opening remains behind the box.
        translate([-plate_w / 2 + cable_edge_offset, 0, -0.01])
            cylinder(d = cable_d, h = plate_t + 0.02);
        translate([0, -plate_h / 2 + cable_edge_offset, -0.01])
            cylinder(d = cable_d, h = plate_t + 0.02);
    }
}

backplate();

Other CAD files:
renders/stl/nubble-basrelief-breaker.stl
renders/stl/nubble-foreground-layer.stl
renders/stl/luminary-7in-p4-backplate.stl
cad/luminary-7in-p4-fit-check.scad
cad/luminary-front-door.scad
cad/nubble-clear-supports.scad
cad/nubble-display-contact-frame.scad
cad/nubble_layers.scad
renders/luminary-concept.blend
renders/luminary-silhouette.stl
renders/luminary-structures.stl
renders/nubble-concept-rear-assembly.blend
renders/nubble-concept-rock-texture-detail.blend
renders/nubble-concept.blend
renders/stl/luminary-7in-p4-fit-check.stl
renders/stl/luminary-backplate.stl
renders/stl/luminary-display-carrier.stl
renders/stl/luminary-silhouette-carrier.stl
renders/stl/luminary-silhouette.stl
renders/stl/luminary-structures.stl

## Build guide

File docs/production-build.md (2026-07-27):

# Luminary production build

## Print set

Print these parts at 0.20 mm layer height unless a slicer-specific strength
test indicates otherwise:

- `renders/stl/luminary-7in-p4-backplate.stl` — matte-black PLA rear plate.
- `renders/stl/luminary-7in-p4-fit-check.stl` — 1 mm low-material test frame;
  verify the actual P4 perimeter and corner holes before printing the backplate.
- `renders/stl/luminary-front-door-reference.stl` — watertight 7 x 5 x 1 in
  woodworking reference for the hinged front door; do not print this wood part.
- `renders/stl/nubble-basrelief-island.stl` — black PLA, 1.6 mm relief.
- `renders/stl/nubble-basrelief-island-texture.stl` — source-derived 0.2 mm
  rock-texture companion; import with the island base STL as one print.
- `renders/stl/nubble-basrelief-breaker.stl` — dark/charcoal PLA, 1.6 mm relief.
- `renders/stl/nubble-basrelief-breaker-texture.stl` — 0.2 mm texture
  companion for the breaker base STL.
- `renders/stl/nubble-basrelief-foreground.stl` — dark/charcoal PLA, 1.8 mm
  relief above its 3.2 mm placement level.
- `renders/stl/nubble-basrelief-foreground-texture.stl` — 0.2 mm texture
  companion for the foreground base STL.
- `renders/stl/nubble-display-contact-frame.stl` — thin 4 x 6 in matte-black
  PLA display-contact frame; it has no front magnets.
- `renders/stl/nubble-clear-supports.stl` — clear-PETG bridge traces and posts
  for isolated shallow layers; this is not a full transparent backing sheet.

The landscape shadow box has a 7 x 5 x 2 in outer enclosure and a hinged,
1 in deep front door. Its distressed-white wood door rails are 0.75 in wide
and frame the 5.5 x 3.5 in glass opening. A 1/8 in deep matching wood
sight-mat sits immediately behind the glass, reducing the visible LCD aperture
to 5.25 x 3.25 in so the P4 bezel and image edge remain hidden; it is wood,
not a separate cardboard/brown mat material.
Two small aged-metal butt hinges mount along the lower horizontal door/frame
seam, each with a horizontal barrel and four visible screw heads.
The P4 sits at the rear, behind the full scene background. Total printed scene
depth is 5.0 mm plus up to 1.35 mm of shallow source-derived rock texture; the
remaining box depth is open air for shadow and parallax.

The Nubble island and the 4 x 6 in contact frame sit directly against the P4
face. A 1.0 mm deep, 0.30 mm clearance rabbet in the rear of the door captures
the 0.8 mm frame flush with the lid inset; the closed door and its wood
sight-mat provide retention. Do not add front magnet pockets. This creates a
black interior reveal that hides the LCD edge and lets distant, zero-parallax
content—weather, changing sea, or seasonal background—live on the display.
Keep physically raised foreground elements separate; a display cannot place
dynamic pixels on opaque black PLA.

Mount the midground peninsula 2.5 mm forward of the LCD contact plane and the foreground
5.0 mm forward. Do not use the unused 2 in box cavity as a 35 mm parallax
gap: source registration visibly fails at normal three-quarter viewing angles.

Print `nubble-clear-supports.stl` in clear PETG at 0.12 mm layers. Its two
breaker posts and two foreground posts locate the shallow relief stack; the
0.45 mm traces begin beneath the black contact-frame margin and remain hidden
by the closed door/sight-mat.

## Rear plate and P4

The plate is 177.8 x 127 x 3 mm with a 166 x 101.6 mm P4 registration land,
four rear-facing 6.2 x 2.1 mm magnet pockets, and both side and bottom-centre
8 mm circular cable exits, each retained by a 1 mm PLA edge wall. Use M2.5
machine screws and washers through the four 6 x
5.2 mm tolerance slots. The slots intentionally allow the mount to match the
actual board-hole pattern, which must be checked against the physical P4 before
final assembly.

Follow [the P4 physical fit-check procedure](p4-fit-check.md) before printing
the structural rear plate. It gives the board-specific pass/fail criteria for
the supplied low-material test ring, M2.5 fasteners, USB-C extension routes,
and rear magnets.

Use four 6 x 2 mm disc magnets (or revise the parameters in
`cad/luminary-7in-backplate.scad` for the magnets on hand) and epoxy matching
steel squares to the back of the wood frame. Confirm magnet polarity before
gluing.

## Verification

The render in `renders/nubble-concept.png` imports the same bas-relief STLs
listed above, not substitute Blender geometry. The scene source, land-free LCD
background, and all relief masks use one 1024 x 600 canvas in
`scenes/nubble-aligned/`.

The 5.5 x 3.5 in relief field is narrower than the P4's native active area.
`scripts/compile-bas-relief.sh` centre-crops the source, LCD background, and
every mask from the identical 943 x 600 source region before mapping them into
that physical field. This is required for parallax layers to line up with the
background at any viewing angle.

`renders/nubble-concept-rear-assembly.png` is the complementary rear
verification render. It imports `luminary-7in-p4-backplate.stl` into the same
assembly, exposing the fastener slots, four magnet pockets, and both circular
cable exits.

Blender mesh audit: the P4 backplate, door reference, island, breaker, and
foreground STLs each have zero non-manifold and zero boundary edges. The P4
registration land clears the 164.28 x 99.17 mm display envelope by 0.86 mm at
each side and 1.215 mm at the top and bottom.

Before each STL release, run `scripts/compile-bas-relief.sh nubble-aligned` and
inspect `scenes/nubble-aligned/compiled/reference-alignment.png`. It overlays
the printable masks on the original source photograph: island in red, breaker
in gold, and foreground rocks in cyan. Reject the export if any contour or
scale does not match the photograph. `scripts/verify-production.sh` regenerates
and size-checks this validation artifact along with the mesh audit.

For Nubble, `scenes/nubble-aligned/breaker-source-segmentation.png` is the
reviewed source-coordinate segmentation for the continuous left-to-centre
midground peninsula, including the breaker where the wave crashes. It replaces
the earlier isolated-rock mask: the breaker is not a floating island.

`scenes/nubble-aligned/island-ai-separation.jpg` is the supplied AI separation
registered to the original photograph by lighthouse and shoreline landmarks.
The compiler preserves its detailed exterior shore contour, while filling its
white structure cutouts into the opaque black island until a separately
validated white-building print layer is introduced.

The three rock STLs include a masked 0–1.35 mm tonal bas-relief sampled from
the original photograph, not a generated replacement image. The compiler
normalizes source tonal structure to retain both broad rock faces and local
cracks, then samples on a 700 x 444 grid (0.20 x 0.20 mm per sample on the
finished field).
It converts those values into three shallow, merged mesh bands rather than a
fragile per-pixel terrain mesh, then removes features below one nozzle width.
Import each texture companion with its base STL and use a 0.12 mm layer height;
retain at least three walls. The source mask is applied before those tiles are
created, so relief cannot extend beyond an opaque rock silhouette.

The approved release must retain
`scenes/nubble-aligned/compiled/background-cropped.png` beside the final
render. It is the exact LCD asset imported by the Blender file and is generated
deterministically by `scripts/compile-bas-relief.sh nubble-aligned`.

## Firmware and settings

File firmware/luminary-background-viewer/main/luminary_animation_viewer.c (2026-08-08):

/*
 * Luminary animation viewer: Waveshare ESP32-P4-WIFI6-Touch-LCD-7B only.
 *
 * 7-inch landscape EK79007 MIPI-DSI panel: 1024 x 600, two DSI lanes,
 * reset GPIO 33. There is deliberately no 5-inch or portrait fallback.
 */

#include <string.h>
#include <math.h>
#include <stdbool.h>
#include <stdlib.h>
#include <stdio.h>
#include <time.h>
#include <errno.h>
#include <sys/stat.h>
#include <unistd.h>

#include "driver/jpeg_decode.h"
#include "driver/sdspi_host.h"
#include "driver/spi_common.h"
#include "cJSON.h"
#include "esp_attr.h"
#include "esp_check.h"
#include "esp_cpu.h"
#include "esp_crc.h"
#include "esp_crt_bundle.h"
#include "esp_heap_caps.h"
#include "esp_http_client.h"
#include "esp_http_server.h"
#include "esp_event.h"
#include "esp_lcd_ek79007.h"
#include "esp_lcd_mipi_dsi.h"
#include "esp_lcd_panel_io.h"
#include "esp_lcd_panel_ops.h"
#include "esp_ldo_regulator.h"
#include "esp_log.h"
#include "esp_timer.h"
#include "driver/temperature_sensor.h"
#include "esp_netif.h"
#include "esp_netif_sntp.h"
#include "esp_vfs_fat.h"
#include "esp_wifi.h"
#include "freertos/FreeRTOS.h"
#include "freertos/event_groups.h"
#include "freertos/semphr.h"
#include "freertos/task.h"
#include "nvs_flash.h"
#include "sdmmc_cmd.h"
#include "sd_pwr_ctrl_by_on_chip_ldo.h"
#include "ocean_sim.h"
#include "luminary_runtime_state.h"
#include "hipparcos_stars.h"

#define LUMINARY_WIDTH                  1024U
#define LUMINARY_HEIGHT                  600U
#define LUMINARY_BPP                        3U
#define LUMINARY_FRAME_BYTES (LUMINARY_WIDTH * LUMINARY_HEIGHT * LUMINARY_BPP)
#define LUMINARY_DECODE_HEIGHT             608U /* JPEG DMA output is 16-line aligned. */
#define LUMINARY_DECODE_BYTES (LUMINARY_WIDTH * LUMINARY_DECODE_HEIGHT * LUMINARY_BPP)
#define LUMINARY_WAVE_CYCLE_MAX_BYTES       (10U * 1024U * 1024U)
#define LUMINARY_WAVE_CYCLE_MAX_FRAME_BYTES  (2U * 1024U * 1024U)

#define LUMINARY_LCD_RESET_GPIO           33
#define LUMINARY_MIPI_LDO_CHANNEL          3
#define LUMINARY_MIPI_LDO_VOLTAGE_MV    2500
#define LUMINARY_MIPI_DSI_LANES            2

#define LUMV_MAGIC 0x564d554cU /* ASCII LUMV, little-endian */
#define LUMV_VERSION 1U

typedef struct __attribute__((packed)) {
    uint32_t magic;
    uint16_t version;
    uint16_t header_bytes;
    uint16_t width;
    uint16_t height;
    uint32_t fps_milli;
    uint32_t frame_count;
    uint32_t index_offset;
    uint32_t data_offset;
} lumv_header_t;

typedef struct __attribute__((packed)) {
    uint32_t offset; /* Absolute offset from the beginning of the LUMV blob. */
    uint32_t length;
} lumv_frame_t;

typedef struct {
    uint8_t *payload;
    size_t payload_bytes;
    const lumv_frame_t *frames;
    uint32_t frame_count;
    uint32_t fps_milli;
} wave_cycle_t;

extern const uint8_t nubble_runtime_base_jpg_start[] asm("_binary_nubble_runtime_base_jpg_start");
extern const uint8_t nubble_runtime_base_jpg_end[] asm("_binary_nubble_runtime_base_jpg_end");
extern const uint8_t nubble_runtime_water_mask_bin_start[] asm("_binary_nubble_runtime_water_mask_bin_start");
extern const uint8_t nubble_runtime_shore_distance_bin_start[] asm("_binary_nubble_runtime_shore_distance_bin_start");
extern const uint8_t nubble_runtime_ocean_phase_bin_start[] asm("_binary_nubble_runtime_ocean_phase_bin_start");
extern const uint8_t nubble_runtime_cloud_low_bin_start[] asm("_binary_nubble_runtime_cloud_low_bin_start");
extern const uint8_t nubble_runtime_cloud_mid_bin_start[] asm("_binary_nubble_runtime_cloud_mid_bin_start");
extern const uint8_t nubble_runtime_cloud_high_bin_start[] asm("_binary_nubble_runtime_cloud_high_bin_start");

static const char *TAG = "luminary-anim";
/* PSRAM copies of the two per-pixel lookup assets the water pass reads. The
 * embedded originals live in flash, and per-pixel flash data reads from the
 * IRAM row loops go through the flash cache path -- the same one that made
 * flash-resident code catastrophically slow here. PSRAM reads share the
 * ordinary data cache with everything else the pass touches. */
static const uint8_t *water_mask_ram;
static const uint8_t *shore_distance_ram;
/* Read only while building the per-frame wave tables (about a thousand reads
 * a frame), so it lives in PSRAM: internal RAM here is what decides whether
 * the firmware boots. This image boot-loops in ESP-Hosted startup once static
 * DIRAM passes roughly 133 KB. */
static int8_t *wave_sine;
/* Hot per-pixel row tables: internal RAM for speed, but from the heap at
 * renderer start rather than .bss -- the static image sits against the
 * ~133 KB DIRAM ceiling where ESP-Hosted startup boot-loops. */
static int8_t *wave_shade_row;
static uint8_t *wave_breaker_phase_row;
/* Three cloud shells composed into one screen-space layer, per half-res
 * column: transmission of the stack and the premultiplied colour it adds.
 * Turns three per-pixel alpha blends across 291 rows into one -- the shells
 * only vary at atlas resolution (256 texels across 1024 pixels), so nothing
 * visible is lost at half-column granularity. Internal heap, allocated after
 * the boot-critical window like the other row scratch. */
static uint8_t *cloud_row_trans;
static uint8_t *cloud_row_add; /* interleaved b, g, r per half-res column */
/* Three-row ring of the authored frame in internal RAM, feeding the water
 * pass's displaced refraction reads. Scattered PSRAM reads of the base frame
 * depend on L2 residency that the solver's 220 KB steps and the die
 * temperature both erode; one sequential 3 KB copy per row is prefetch-
 * friendly and immune to either, and every displaced read after it is
 * internal-RAM cheap. Slot = row % 3. */
static uint8_t *base_row_ring;

/* 4x4 ordered dither for the shade quantisation, 0..15. Read once per water
 * pixel from an IRAM loop, so it must be RAM: written at renderer start
 * precisely so the compiler cannot const-promote it into flash rodata --
 * which it did to the initialised version of this table. */
static uint8_t shade_dither[4][4];
#if CONFIG_LUMINARY_OCEAN_SIM
/* Per-cell foam from the shallow-water solver, 0..254; 255 means "no solver
 * data here, use the analytic crest heuristic". Read per water pixel, so it
 * must be internal RAM -- but from the heap at renderer start, not .bss:
 * the static image sits against the boot DIRAM ceiling. */
static uint8_t *wave_foam_row;
/* Per-cell texture displacement in panel pixels, from the solver's surface
 * gradient. Shading alone reads as a light wash over a still photograph --
 * the authored texture's own chop stays frozen. Refracting the source
 * lookup through the moving surface makes that texture itself move. */
static int8_t *wave_dx_row;
static int8_t *wave_dy_row;
#endif

/* Per-phase render profiling, off by default. Each phase of the frame is
 * timed and reported alongside the cadence log, which is how the render budget
 * was attributed; enable CONFIG_LUMINARY_RENDER_PROFILING to get it back. The
 * timing calls are compiled out entirely when it is off, so the shipping path
 * pays nothing for them. */
#if CONFIG_LUMINARY_RENDER_PROFILING
static int64_t prof_basecopy_us, prof_lut_us, prof_wave_us,
               prof_sky_us, prof_water_us, prof_stars_us, prof_fbcopy_us;
#define PROF_STAMP(name)        const int64_t name = esp_timer_get_time()
#define PROF_STAMP_MUT(name)    int64_t name = esp_timer_get_time()
#define PROF_RESTAMP(name)      name = esp_timer_get_time()
#define PROF_ADD(acc, from, to) ((acc) += (to) - (from))
#define PROF_SET(acc, from)     ((acc) = esp_timer_get_time() - (from))
#define PROF_ZERO(...)          do { __VA_ARGS__; } while (0)
#else
#define PROF_STAMP(name)        ((void)0)
#define PROF_STAMP_MUT(name)    ((void)0)
#define PROF_RESTAMP(name)      ((void)0)
#define PROF_ADD(acc, from, to) ((void)0)
#define PROF_SET(acc, from)     ((void)0)
#define PROF_ZERO(...)          ((void)0)
#endif

/* Measured: esp_async_memcpy (DMA) for this 1.84 MB PSRAM->PSRAM copy came in
 * at 47.0 ms against 45.9 ms for plain memcpy. The transfer is bandwidth
 * bound, not CPU bound, so DMA buys nothing and costs an ISR round trip.
 * Folding the copy into the per-row work is the promising direction instead. */
/* 12 KB, the largest single static object this firmware had. Internal heap
 * at renderer start instead of .bss: same DRAM, same speed, but it no longer
 * counts against the boot-time DIRAM ceiling that ESP-Hosted startup
 * enforces. Indexed as [channel][shade][source]. */
typedef uint8_t wave_color_lut_t[3][16][256];
static wave_color_lut_t *wave_color_lut_mem;
#define wave_color_lut (*wave_color_lut_mem)
/* PSRAM: read three times per quarter-res column by the cloud compose, not
 * per pixel. Freed 1 KB of the internal budget for the IRAM row loop. */
static uint8_t *cloud_x_lut;
/* Three reads per sky row against one per pixel for cloud_x_lut: the row
 * table can afford PSRAM, the column table cannot. */
static uint8_t *cloud_y_lut;

typedef struct {
    uint8_t *atlas; /* Interleaved luminance, alpha. */
    int32_t wind_east_mmps;
    int32_t wind_north_mmps;
    uint32_t height_m;
    uint8_t blue_bias;
} cloud_shell_t;

typedef struct {
    uint32_t height_mm;
    uint32_t period_ms;
} wave_component_t;

typedef struct {
    uint16_t cloud_cover_permille;
    uint8_t sky_r, sky_g, sky_b;
    uint8_t sun_mode; /* 0 day, 1 civil, 2 nautical, 3 night */
    int16_t sun_altitude_deci_deg;
    int16_t sun_relative_azimuth_deci_deg;
    bool moon_visible;
    int16_t moon_x, moon_y;
    uint16_t moon_illumination_permille;
    uint32_t wave_height_mm;
    uint32_t wave_period_ms;
    int32_t wave_kx_q10, wave_ky_q10;
    uint8_t wave_component_count;
    wave_component_t waves[3];
    uint8_t *ocean_phase;
    cloud_shell_t shells[3]; /* high, mid, low */
} runtime_state_t;

static runtime_state_t runtime_state;
static SemaphoreHandle_t runtime_lock;
static wave_cycle_t runtime_wave_cycle;
static const uint8_t *current_framebuffer;

typedef struct {
    int16_t x, y;
    uint8_t intensity;
    uint8_t radius;
} visible_star_t;

#define MAX_VISIBLE_STARS 512U
// Written once per solar update and read once per frame, so it has no
// business occupying internal RAM. Moving it to PSRAM frees 3 KB of the
// internal budget for the IRAM render loops, which do need the speed.
static visible_star_t *visible_stars;
static unsigned visible_star_count;

#define CLOUD_ATLAS_BYTES (LUMINARY_CLOUD_TEXTURE_WIDTH * LUMINARY_CLOUD_TEXTURE_HEIGHT * 2U)
#define OCEAN_PHASE_WIDTH  (LUMINARY_WIDTH / 2U)
#define OCEAN_PHASE_HEIGHT (LUMINARY_HEIGHT / 2U)
#define OCEAN_PHASE_COMPONENTS 3U
#define OCEAN_PHASE_BYTES (OCEAN_PHASE_WIDTH * OCEAN_PHASE_HEIGHT * OCEAN_PHASE_COMPONENTS)
#define RUNTIME_MANIFEST_MAX_BYTES 8192U
#define RUNTIME_STATE_MAX_BYTES    8192U
#define RUNTIME_URL_MAX_BYTES       512U
#define RUNTIME_PATH_MAX_BYTES      160U
#define SD_CACHE_MAGIC       0x434d554cU /* ASCII LUMC, little-endian */
#define SD_CACHE_VERSION             1U
#define SD_CACHE_MOUNT       "/sdcard"
#define SD_CACHE_DIRECTORY   SD_CACHE_MOUNT "/luminary"
/* Keep cache leaf names FAT 8.3-compatible; long-filename support is deliberately
 * disabled in this small embedded build. */
#define SD_CACHE_SLOT_A      SD_CACHE_DIRECTORY "/RUN_A.BIN"
#define SD_CACHE_SLOT_B      SD_CACHE_DIRECTORY "/RUN_B.BIN"
#define YORK_LATITUDE_DEG        43.1637
#define YORK_LONGITUDE_DEG      -70.6480
#define NUBBLE_CAMERA_BEARING_DEG    90.0

#define WIFI_CONNECTED_BIT BIT0
#define WIFI_FAILED_BIT    BIT1

static EventGroupHandle_t wifi_events;
static unsigned wifi_retry_count;
static char active_bundle_id[48];
static bool sd_cache_available;
static uint64_t sd_cache_sequence;

typedef struct __attribute__((packed)) {
    uint32_t magic;
    uint16_t version;
    uint16_t header_bytes;
    uint64_t sequence;
    uint32_t payload_crc32;
    uint32_t state_bytes;
    uint32_t cloud_bytes;
    uint32_t ocean_bytes;
    char bundle_id[48];
} sd_cache_header_t;

static bool parse_lumv_cycle(const uint8_t *payload, size_t payload_bytes,
                             uint32_t *frame_count, uint32_t *fps_milli,
                             const lumv_frame_t **frames_out);
static void release_wave_cycle_locked(void);
static bool valid_state_root(cJSON *root);
static void apply_state_root_locked(cJSON *root);

static void wifi_event_handler(void *argument, esp_event_base_t event_base,
                               int32_t event_id, void *event_data)
{
    (void)argument;
    if (event_base == WIFI_EVENT && event_id == WIFI_EVENT_STA_START) {
        ESP_ERROR_CHECK_WITHOUT_ABORT(esp_wifi_connect());
    } else if (event_base == WIFI_EVENT && event_id == WIFI_EVENT_STA_DISCONNECTED) {
        xEventGroupClearBits(wifi_events, WIFI_CONNECTED_BIT);
        if (wifi_retry_count++ < CONFIG_LUMINARY_WIFI_MAXIMUM_RETRY) {
            ESP_ERROR_CHECK_WITHOUT_ABORT(esp_wifi_connect());
        } else {
            xEventGroupSetBits(wifi_events, WIFI_FAILED_BIT);
        }
    } else if (event_base == IP_EVENT && event_id == IP_EVENT_STA_GOT_IP) {
        const ip_event_got_ip_t *event = event_data;
        wifi_retry_count = 0;
        ESP_LOGI(TAG, "Wi-Fi connected; IPv4=" IPSTR, IP2STR(&event->ip_info.ip));
        xEventGroupSetBits(wifi_events, WIFI_CONNECTED_BIT);
    }
}

static void start_wifi(void)
{
    if (CONFIG_LUMINARY_WIFI_SSID[0] == '\0') {
        ESP_LOGW(TAG, "Wi-Fi disabled: no local SSID configured");
        return;
    }

    esp_err_t result = nvs_flash_init();
    if (result == ESP_ERR_NVS_NO_FREE_PAGES || result == ESP_ERR_NVS_NEW_VERSION_FOUND) {
        ESP_ERROR_CHECK(nvs_flash_erase());
        result = nvs_flash_init();
    }
    ESP_ERROR_CHECK(result);
    ESP_ERROR_CHECK(esp_netif_init());
    ESP_ERROR_CHECK(esp_event_loop_create_default());
    ESP_ERROR_CHECK(esp_netif_create_default_wifi_sta() ? ESP_OK : ESP_ERR_NO_MEM);

    wifi_events = xEventGroupCreate();
    ESP_ERROR_CHECK(wifi_events ? ESP_OK : ESP_ERR_NO_MEM);
    wifi_init_config_t init_config = WIFI_INIT_CONFIG_DEFAULT();
    ESP_ERROR_CHECK(esp_wifi_init(&init_config));
    ESP_ERROR_CHECK(esp_event_handler_register(WIFI_EVENT, ESP_EVENT_ANY_ID,
                                               wifi_event_handler, NULL));
    ESP_ERROR_CHECK(esp_event_handler_register(IP_EVENT, IP_EVENT_STA_GOT_IP,
                                               wifi_event_handler, NULL));

    wifi_config_t station = {0};
    strlcpy((char *)station.sta.ssid, CONFIG_LUMINARY_WIFI_SSID,
            sizeof(station.sta.ssid));
    strlcpy((char *)station.sta.password, CONFIG_LUMINARY_WIFI_PASSWORD,
            sizeof(station.sta.password));
    station.sta.threshold.authmode = WIFI_AUTH_WPA2_PSK;
    ESP_ERROR_CHECK(esp_wifi_set_mode(WIFI_MODE_STA));
    ESP_ERROR_CHECK(esp_wifi_set_config(WIFI_IF_STA, &station));
    ESP_ERROR_CHECK(esp_wifi_start());
    const esp_sntp_config_t sntp_config = ESP_NETIF_SNTP_DEFAULT_CONFIG("time.cloudflare.com");
    ESP_ERROR_CHECK(esp_netif_sntp_init(&sntp_config));
    ESP_LOGI(TAG, "Connecting to Wi-Fi SSID '%s'", CONFIG_LUMINARY_WIFI_SSID);
}

static double wrap_degrees(double value)
{
    value = fmod(value, 360.0);
    return value < 0.0 ? value + 360.0 : value;
}
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
void app_main(void)
{
    initialize_runtime_state();
    mount_and_load_sd_cache();
    start_wifi();
    if (CONFIG_LUMINARY_WIFI_SSID[0] != '\0') {
        start_runtime_server();
    } else {
        ESP_LOGW(TAG, "Runtime API endpoints disabled: Wi-Fi SSID not configured");
    }

    const uint8_t *asset = nubble_runtime_base_jpg_start;
    const size_t asset_size = nubble_runtime_base_jpg_end - asset;

    esp_ldo_channel_handle_t mipi_ldo = NULL;
    esp_lcd_dsi_bus_handle_t dsi_bus = NULL;
    esp_lcd_panel_io_handle_t dbi_io = NULL;
    esp_lcd_panel_handle_t panel = NULL;

    const esp_ldo_channel_config_t ldo_config = {
        .chan_id = LUMINARY_MIPI_LDO_CHANNEL,
        .voltage_mv = LUMINARY_MIPI_LDO_VOLTAGE_MV,
    };
    ESP_ERROR_CHECK(esp_ldo_acquire_channel(&ldo_config, &mipi_ldo));
    const esp_lcd_dsi_bus_config_t dsi_config = EK79007_PANEL_BUS_DSI_2CH_CONFIG();
    ESP_ERROR_CHECK(esp_lcd_new_dsi_bus(&dsi_config, &dsi_bus));
    const esp_lcd_dbi_io_config_t dbi_config = EK79007_PANEL_IO_DBI_CONFIG();
    ESP_ERROR_CHECK(esp_lcd_new_panel_io_dbi(dsi_bus, &dbi_config, &dbi_io));

    // The physical 7B panel scans RGB888. RGB565 is accepted by the API but
    // is read as 24-bit scanout on this board, producing cyan/magenta noise.
    esp_lcd_dpi_panel_config_t dpi_config = EK79007_1024_600_PANEL_60HZ_CONFIG(LCD_COLOR_PIXEL_FORMAT_RGB888);
    dpi_config.num_fbs = 2; /* Decode into the inactive frame, then swap it in. */
    ek79007_vendor_config_t vendor_config = {
        .mipi_config = {
            .dsi_bus = dsi_bus,
            .dpi_config = &dpi_config,
            .lane_num = LUMINARY_MIPI_DSI_LANES,
        },
    };
    const esp_lcd_panel_dev_config_t panel_config = {
        .reset_gpio_num = LUMINARY_LCD_RESET_GPIO,
        .rgb_ele_order = LCD_RGB_ELEMENT_ORDER_RGB,
        .bits_per_pixel = 24,
        .vendor_config = &vendor_config,
    };
    ESP_ERROR_CHECK(esp_lcd_new_panel_ek79007(dbi_io, &panel_config, &panel));
    ESP_ERROR_CHECK(esp_lcd_panel_reset(panel));
    ESP_ERROR_CHECK(esp_lcd_panel_init(panel));
    // EK79007 has no esp_lcd_panel_disp_on_off implementation. Panel init
    // already enables it; treating ESP_ERR_NOT_SUPPORTED as fatal causes a
    // reboot loop and the visible cyan flash on the 7B.

    uint8_t *framebuffer[2] = {NULL, NULL};
    ESP_ERROR_CHECK(esp_lcd_dpi_panel_get_frame_buffer(panel, 2, (void **)&framebuffer[0], (void **)&framebuffer[1]));
    uint8_t *render_buffer = heap_caps_malloc(LUMINARY_FRAME_BYTES,
                                               MALLOC_CAP_SPIRAM | MALLOC_CAP_8BIT);
    ESP_ERROR_CHECK(render_buffer ? ESP_OK : ESP_ERR_NO_MEM);

    jpeg_decode_memory_alloc_cfg_t input_config = {.buffer_direction = JPEG_DEC_ALLOC_INPUT_BUFFER};
    jpeg_decode_memory_alloc_cfg_t output_config = {.buffer_direction = JPEG_DEC_ALLOC_OUTPUT_BUFFER};
    size_t input_capacity = 0;
    size_t decoded_capacity = 0;
    const size_t minimum_input_capacity = LUMINARY_WAVE_CYCLE_MAX_FRAME_BYTES + 4096U;
    uint8_t *input = jpeg_alloc_decoder_mem(minimum_input_capacity, &input_config, &input_capacity);
    uint8_t *decoded = jpeg_alloc_decoder_mem(LUMINARY_DECODE_BYTES, &output_config, &decoded_capacity);
    ESP_ERROR_CHECK(input && decoded && decoded_capacity >= LUMINARY_DECODE_BYTES ? ESP_OK : ESP_ERR_NO_MEM);
    if (input_capacity < minimum_input_capacity) {
        ESP_LOGW(TAG, "JPEG input capacity %zu is below %zu; wave-cycle decode may fall back",
                 input_capacity, minimum_input_capacity);
    }

    jpeg_decoder_handle_t decoder = NULL;
    const jpeg_decode_engine_cfg_t engine_config = {.timeout_ms = 60};
    const jpeg_decode_cfg_t decode_config = {
        .output_format = JPEG_DECODE_OUT_FORMAT_RGB888,
        // The EK79007's RGB888 scanout consumes B,G,R byte order from the
        // P4 framebuffer even though the panel's logical element order is
        // RGB.  Supplying decoder RGB here makes blue sky render sepia/red.
        .rgb_order = JPEG_DEC_RGB_ELEMENT_ORDER_BGR,
        .conv_std = JPEG_YUV_RGB_CONV_STD_BT601,
    };
    ESP_ERROR_CHECK(jpeg_new_decoder_engine(&engine_config, &decoder));

    ESP_ERROR_CHECK(asset_size <= input_capacity ? ESP_OK : ESP_ERR_INVALID_SIZE);
    memcpy(input, asset, asset_size);
    jpeg_decode_picture_info_t info = {0};
    ESP_ERROR_CHECK(jpeg_decoder_get_info(input, asset_size, &info));
    ESP_ERROR_CHECK(info.width == LUMINARY_WIDTH && info.height == LUMINARY_HEIGHT ? ESP_OK : ESP_ERR_INVALID_SIZE);
    uint32_t decoded_size = 0;
    ESP_ERROR_CHECK(jpeg_decoder_process(decoder, &decode_config, input, asset_size,
                                         decoded, decoded_capacity, &decoded_size));
    ESP_ERROR_CHECK(decoded_size >= LUMINARY_FRAME_BYTES ? ESP_OK : ESP_ERR_INVALID_SIZE);
    uint8_t *base_decoded = heap_caps_malloc(LUMINARY_FRAME_BYTES, MALLOC_CAP_SPIRAM | MALLOC_CAP_8BIT);
    if (!base_decoded) {
        ESP_ERROR_CHECK(ESP_ERR_NO_MEM);
    }
    memcpy(base_decoded, decoded, LUMINARY_FRAME_BYTES);
    initialize_wave_lut();
    if (wifi_events && CONFIG_LUMINARY_RUNTIME_BASE_URL[0] != '\0') {
        ESP_ERROR_CHECK(xTaskCreate(runtime_pull_task, "runtime-pull", 16384, NULL, 3, NULL) == pdPASS ?
                        ESP_OK : ESP_ERR_NO_MEM);
        ESP_LOGI(TAG, "Autonomous runtime polling: %s every %u seconds",
                 CONFIG_LUMINARY_RUNTIME_BASE_URL, CONFIG_LUMINARY_RUNTIME_POLL_SECONDS);
    }

#if CONFIG_LUMINARY_OCEAN_SIM
    if (ocean_sim_start()) {
        xSemaphoreTake(runtime_lock, portMAX_DELAY);
        ocean_sim_apply_conditions_locked();
        xSemaphoreGive(runtime_lock);
        // CPU1 runs this render loop, so the solver gets CPU0.
        ESP_ERROR_CHECK(xTaskCreatePinnedToCore(ocean_sim_task, "ocean-sim", 4096,
                                                NULL, 4, NULL, 0) == pdPASS ?
                        ESP_OK : ESP_ERR_NO_MEM);
        ESP_LOGI(TAG, "Ocean solver: %ux%u cells at %u Hz on CPU0, %u KB in PSRAM",
                 OCEAN_NX, OCEAN_NY, CONFIG_LUMINARY_OCEAN_SIM_HZ,
                 (unsigned)((OCEAN_CELLS * 6u) / 1024u));
    }
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

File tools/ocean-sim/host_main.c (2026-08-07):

/* Host driver for the Luminary shallow-water prototype.
 *
 * Builds a synthetic bathymetry, runs the solver, writes PPM frames and
 * reports numerical checks. No hardware and no ESP-IDF involved: the solver
 * source here is the same file destined for firmware/.../main/.
 *
 *   make && ./ocean-sim --steps 900 --frames output/ocean-sim
 */
#include "ocean_sim.h"

#include <stdio.h>
#include <stdlib.h>
#include <string.h>
#include <math.h>

#ifndef M_PI
#define M_PI 3.14159265358979323846
#endif

static int16_t g_h[OCEAN_CELLS];
static int16_t g_vel[OCEAN_CELLS];
static uint8_t g_depth[OCEAN_CELLS];
static int8_t  g_normal[2 * OCEAN_CELLS];
static uint8_t g_foam[OCEAN_CELLS];
static uint16_t g_damp_residual[OCEAN_CELLS];

/* Placeholder bathymetry: a curved shoreline at low y, a linear depth ramp out
 * to 30 m, and a rock stack offshore. Real bathymetry must come from the scene
 * geometry -- see the note at the end of build_depth(). */
static double shoreline_y(unsigned x)
{
    const double t = (double)x / (double)OCEAN_NX;
    return 6.0 + 4.0 * sin(t * 2.0 * 2.0 * M_PI);
}

static int g_flat = 0;
static int g_freefield = 0;
static const char *g_depth_file = NULL;

static void build_depth(void)
{
    if (g_depth_file) {
        FILE *f = fopen(g_depth_file, "rb");
        if (!f) { perror(g_depth_file); exit(1); }
        const size_t got = fread(g_depth, 1, OCEAN_CELLS, f);
        fclose(f);
        if (got != OCEAN_CELLS) {
            fprintf(stderr, "depth file %s: expected %u bytes, got %zu\n",
                    g_depth_file, OCEAN_CELLS, got);
            exit(1);
        }
        return;
    }
    if (g_flat) {
        /* Uniform deep basin, no land at all: isolates the integrator from the
         * shore and rock boundary handling. */
        for (size_t i = 0; i < OCEAN_CELLS; ++i) g_depth[i] = 255u;
        return;
    }
    const double rock_x = OCEAN_NX * 0.45;
    const double rock_y = 30.0;
    const double rock_r = 7.0;

    for (unsigned y = 0; y < OCEAN_NY; ++y) {
        for (unsigned x = 0; x < OCEAN_NX; ++x) {
            const size_t i = (size_t)y * OCEAN_NX + x;
            const double shore = shoreline_y(x);

            const double dx = (double)x - rock_x;
            const double dy = (double)y - rock_y;
            if (dx * dx + dy * dy < rock_r * rock_r) {
                g_depth[i] = OCEAN_DEPTH_LAND;
                continue;
            }
            if ((double)y <= shore) {
                g_depth[i] = OCEAN_DEPTH_LAND;
                continue;
            }
            double t = ((double)y - shore) / ((double)(OCEAN_NY - 1u) - shore);
            if (t < 0.0) t = 0.0;
            if (t > 1.0) t = 1.0;
            unsigned code = (unsigned)(t * 255.0 + 0.5);
            if (code == 0u) code = 1u; /* keep water wet next to the shore */
            g_depth[i] = (uint8_t)code;
        }
    }
    /* TODO: derive from the scene rather than this analytic profile. The
     * existing shore-distance map is image-space only; a world-space depth
     * field needs the sea-plane projection plus the DEM work in scripts/. */
}

static void write_ppm(const ocean_sim_t *sim, const char *path)
{
    FILE *f = fopen(path, "wb");
    if (!f) { perror(path); return; }
    fprintf(f, "P6\n%u %u\n255\n", OCEAN_NX, OCEAN_NY);
    for (unsigned y = 0; y < OCEAN_NY; ++y) {
        /* Draw with the shore at the bottom so it reads like the scene. */
        const unsigned row = OCEAN_NY - 1u - y;
        for (unsigned x = 0; x < OCEAN_NX; ++x) {
            const size_t i = (size_t)row * OCEAN_NX + x;
            unsigned char rgb[3];
            if (sim->depth[i] == OCEAN_DEPTH_LAND) {
                rgb[0] = 70; rgb[1] = 62; rgb[2] = 56;
            } else {
                const int v = sim->h[i];
                const int mag = v > 0 ? v : -v;
                int level = mag * 255 / 3000;
                if (level > 255) level = 255;
                if (v >= 0) {
                    rgb[0] = (unsigned char)(30 + level * 0.85);
                    rgb[1] = (unsigned char)(70 + level * 0.72);
                    rgb[2] = (unsigned char)(110 + level * 0.56);
                } else {
                    rgb[0] = (unsigned char)(30 - level * 0.10 + 0.5);
                    rgb[1] = (unsigned char)(50 - level * 0.15 + 0.5);
                    rgb[2] = (unsigned char)(90 - level * 0.25 + 0.5);
                }
                const unsigned foam = sim->foam[i];
                if (foam) {
                    for (unsigned c = 0; c < 3u; ++c) {
                        rgb[c] = (unsigned char)(rgb[c] + (255 - rgb[c]) * foam / 255);
                    }
                }
            }
            fwrite(rgb, 1, 3, f);
        }
    }
    fclose(f);
}

/* Mean zero-crossing spacing down a column, within [y0,y1). Two crossings per
 * wavelength, so spacing * 2 is the local wavelength in cells. */
static double column_wavelength(const ocean_sim_t *sim, unsigned x,
                                unsigned y0, unsigned y1, int *crossings_out)
{
    /* Remove the band mean: residual DC from the start transient would
     * otherwise bias every sample to one sign and hide the crossings. */
    double mean = 0.0;
    for (unsigned y = y0; y < y1; ++y) mean += sim->h[(size_t)y * OCEAN_NX + x];
    mean /= (double)(y1 - y0);

    double first = -1.0, last = -1.0;
    int crossings = 0;
    for (unsigned y = y0 + 1u; y < y1; ++y) {
        const double a = sim->h[(size_t)(y - 1u) * OCEAN_NX + x] - mean;
        const double b = sim->h[(size_t)y * OCEAN_NX + x] - mean;
        if ((a <= 0 && b > 0) || (a >= 0 && b < 0)) {
            if (first < 0.0) first = y;
            last = y;
            crossings++;
        }
    }
    if (crossings_out) *crossings_out = crossings;
    if (crossings < 2) return 0.0;
    return (last - first) / (double)(crossings - 1) * 2.0;
}

/* Shallow-water wavelength in cells for a given depth code and period. */
static double predicted_cells(const ocean_sim_t *sim, uint8_t code, uint32_t period_ms)
{
    const double d_m = ocean_depth_mm(code) / 1000.0;
    const double c = sqrt(9.81 * d_m);
    return c * ((double)period_ms / 1000.0) / ((double)sim->dx_mm / 1000.0);
}
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

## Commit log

2026-07-26 Add layered coastal silhouette reference
    [lightbox.scad]
2026-07-26 Finish Luminary CAD and Blender concept render
    [lightbox.scad, luminary-carrier.stl, luminary-concept.blend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]
2026-07-26 Add printed rear plate and side USB-C mount
    [lightbox.scad, luminary-concept.blend]
2026-07-26 Make mockup frame distressed white
    [luminary-concept.blend]
2026-07-26 Model glass steel square magnetic attachment
    [lightbox.scad, luminary-glass-hardware.stl]
2026-07-26 Generate land-only silhouette plate
    [lightbox.scad, luminary-concept.blend, luminary-silhouette.stl]
2026-07-26 Set display nearly flush with rear plate
    [lightbox.scad, luminary-concept.blend]
2026-07-26 Use circular USB-C cable pass-through
    [lightbox.scad]
2026-07-26 Add side and bottom cable exits
    [lightbox.scad]
2026-07-26 Render Luminary from a three-quarter angle
    [luminary-concept.blend]
2026-07-26 Render deep shadow box with distressed wood texture
    [lightbox.scad, luminary-concept.blend]
2026-07-26 Fit Luminary stack within 2 inch shadow box
    [lightbox.scad, luminary-concept.blend]
2026-07-26 Add thin silhouette mounting frame and magnet pods
    [lightbox.scad]
2026-07-26 Hide silhouette mount beneath glass rabbet
    [lightbox.scad]
2026-07-26 Finish printable Luminary shadow-box assembly
    [lightbox.scad, luminary-backplate.stl, luminary-concept.blend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]
2026-07-26 Add reusable landscape photo workflow
    [lightbox.scad, luminary-concept.blend]
2026-07-26 Add Nubble three-layer source run
    [lightbox.scad, luminary-concept.blend, luminary-silhouette.stl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]
2026-07-26 Extract and render Nubble magnetic layers
    [nubble-breaker-layer.stl, nubble-concept.blend, nubble-foreground-layer.stl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]
2026-07-26 Register Nubble layers to display background
    [nubble-breaker-layer.stl, nubble-concept.blend, nubble-foreground-layer.stl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]
2026-07-26 Package 7-inch Luminary production candidate
    [bas_relief_scene.scad, luminary-7in-backplate.scad, luminary-7in-p4-backplate.stl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]
2026-07-26 Increase P4 mounting slot tolerance
    [luminary-7in-backplate.scad, luminary-7in-p4-backplate.stl]
2026-07-26 Add P4 physical fit-check frame
    [luminary-7in-p4-fit-check.scad, luminary-7in-p4-fit-check.stl]
2026-07-26 Add recessed P4 bezel sight mat
    [luminary-front-door-reference.stl, luminary-front-door.scad, nubble-concept.blend]
2026-07-26 Verify rear plate cable exits in Blender
    [luminary-7in-backplate.scad, luminary-7in-p4-backplate.stl, nubble-concept-rear-assembly.blend]
2026-07-27 Build Luminary Nubble bas-relief production package
    [bas_relief_scene.scad, lightbox.scad, luminary-concept.blend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]
2026-08-04 Make P4 fetch live runtime autonomously
    [partitions.csv]
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2026-08-07 Cut the P4 frame from 3.5 s to 200 ms
    The renderer was missing its frame deadline by more than an order of
    magnitude. Three findings, each measured on target over UART:
    Instruction fetch from flash dominated, not memory bandwidth. The same
    fused wave loop costs 244 cycles per phase cell executing from flash and
    40 from IRAM. An earlier experiment concluded IRAM placement did not
    matter, but render_runtime_frame is inlined into its caller, so IRAM_ATTR
    placed nothing. noinline is load-bearing here: when the wave loop later
    moved out and freed the inlining budget, GCC pulled grade_sky_row back
    into flash and the sky phase went from 27 ms to 1111 ms.
    The wave field was not paying for the sine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
    [luminary_animation_viewer.c]
2026-08-07 Match the committed runtime to the deployed P4
    The board has been running assets and a scene state that were never
    committed, so a fresh checkout did not reproduce what is on the panel.
    Bring the runtime assets, the generated state header and the scene
    description in line with the deployed bundle.
    Pin the build settings the measured frame budget depends on in
    sdkconfig.defaults. CPU frequency, hex-mode PSRAM, and the L2 cache
    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
2026-08-07 Add the shallow-water ocean solver and its host harness
    Fixed-point explicit finite-difference wave equation with depth-dependent
    celerity, c^2 = g*d. Shoaling and refraction emerge from the bathymetry
    instead of being authored, which is why this suits a shore-dominated scene
    better than a Tessendorf spectrum. Everything is integer maths so the host
    harness and the target produce identical results, and the solver is
    written to drop into the firmware verbatim.
    The grid is sized so h, vel and depth together stay inside the P4's 128 KB
    L2 cache. Buffers are caller-owned by design: on target they have to come
    from PSRAM, the internal heap has no room for them.
    Running against the measured Nubb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
    [host_main.c, ocean_sim.h]
2026-08-07 Derive the solver bathymetry from measured NOAA elevations
    Depth and topography both come from the NOAA NCEI CUDEM 1/9 arc-second
    model, which merges lidar topography with hydrographic bathymetry across
    the shoreline and so actually covers the surf zone. The other two sources
    in data/nubble do not: the multibeam BAG's nearest sounding is ~450 m
    offshore, and the 2017 lidar DEM is topography only.
    The domain is anchored on Cape Neddick Light in a local metric frame taken
    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
2026-08-07 Run the shallow-water solver on the P4's idle core
    The solver sources drop into main/ unchanged, as they were written to.
    The only edit is an OCEAN_SIM_HOT annotation on the two hot functions,
    which expands to IRAM_ATTR plus noinline on target and to nothing on the
    host, so tools/ and main/ stay identical.
    Measured on target at 192x128 cells, 2 m bathymetry, 30 Hz: a step costs
    16.1 ms typical and 24.2 ms at peak against a 33.3 ms budget, so the
    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
2026-08-07 Make the solver propagate honestly instead of by accident
    Three numerical defects, each found by measurement, each of which alone
    made the sea look wrong on the panel:
    Truncation toward zero in the fixed-point multiply and in the height
    update opposed the signal on every step, which is amplitude-proportional
    damping. On the flat deep test domain a swell arrived at the mid-domain
    probe at 27% of its height; rounding to nearest carries it at full
    height. This was the real reason the sheltered channel showed zero wave
    energy -- not the interface depth.
    Rounding to nearest, applied naively to the damping multiply, does the
    opposite damage: 0.9995 * v rounds back to v for |v| below about a
    thou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
    [host_main.c, ocean_sim.h]
2026-08-07 Recover the camera projection the scene never recorded
    The solver works in world space; the panel is a locked photographic view
    of that space. Registering one to the other needs the camera's eye
    height, focal length, yaw and position, none of which were recorded
    anywhere -- the scene JSON carries only the bearing and the horizon row.
    fit-sea-plane-projection.py recovers all of it from measured data. The
    island waterline in the runtime water mask -- the bottom edge of the
    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
2026-08-07 Move the water, not a light show over it
    Two problems with the first solver-driven render, both visible in the
    near field where one 2 m solver cell spans tens of screen pixels.
    The shade LUT has sixteen levels, and at that magnification each level
    step drew a hard terrace across the cell -- the sea looked tiled. Shade
    rows now carry four extra bits of precision everywhere (both solver and
    analytic paths, so the water pass handles one representation) and the
    quantisation is spread by a 4x4 ordered dither. The dither table lives
    in .data deliberately: it is read once per water pixel from an IRAM
    loop, and rodata would put that read on the flash path.
    The deeper problem: shading alone reads a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
    [luminary_animation_viewer.c]
2026-08-07 Optimize the frame around what the measurements actually said
    Every number in this commit was measured on target, most of them twice,
    because the live scene kept changing under the measurements: cloud cover
    moved 0 -> 200 -> 1000/1000, the buoy swell built and faded, and a new
    runtime bundle landed mid-session. Three earlier conclusions in this file
    were artifacts of exactly that and are corrected here.
    The wins, like-for-like:
    Cloud compositing composes the three shells once per quarter-res column
    into one transmission-plus-colour layer, then blends each pixel once
    instead of three times: 96 -> 67 ms at full overcast. Shell-outer,
    column-inner: the pixel-outer compose collapsed to 1.2M cy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
    [luminary_animation_viewer.c]
2026-08-07 Restore the water pass's lost IRAM placement; halve solver field refresh
    Two keepers from a fluidity session that was otherwise defeated by the
    bench itself.
    render_water_row lost its noinline + IRAM_ATTR line in a refactor splice
    several commits ago -- the splice copied the function body starting at
    "static void", silently dropping the attribute line above it. The pass
    ran inlined in app_main, executing from flash, for hours of subsequent
    measurement: 63 ms one build, 940 ms another, with the swings variously
    misattributed to sea state, base-copy strategy, and frame pacing before
    the missing symbol in the ELF gave it away. Third occurrence of this
    exact trap in this file; the comment now s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
    [luminary_animation_viewer.c]
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2026-08-08 Make the sea fluid: 3 fps to 8 fps by redrawing only what moves
    Re-landing of the fluidity rework prototyped two nights ago, this time
    against a bench that can be trusted: the cold-boot experiment confirmed
    the late-night 2-8x slowdown was thermal (same binary: 790 ms at 41.6 C,
    215 ms at 29 C -- the PSRAM steps up temperature-compensated refresh
    around 40 C and scattered reads pay for it).
    Three changes:
    Water-only frames. The sky changes on 30-second solar updates and
    minutes-long cloud drift; the water moves every frame. Each framebuffer
    now refreshes its own sky every 24th of its frames -- a couple of
    seconds of staleness, and the user asked for the sky to move slower
    anyway -- so the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
    [luminary_animation_viewer.c]
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2026-08-09 Run the Android ocean at a 1 m CFD grid (4x finer)
    The 192x192 / 2 m grid was the P4's ceiling, set by its L2 cache and
    DIRAM, not by the physics. On the phone the same solver runs 384x384 over
    the identical 384x384 m domain -- 1 m cells, four times the resolution,
    genuinely finer waves: shorter resolved wavelengths, sharper shoaling and
    refraction around the island, tighter breaker lines (host breaking-cell
    count went 200 -> 1010).
    Per-pixel CFD in screen space is deliberately NOT done: the screen is a
    perspective projection of a tilted plane, so screen pixels map to
    world-space areas varying ~100:1 from foreground to horizon, and a
    uniform-dx finite-difference scheme cannot live on that g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
    [ocean_sim.h]
2026-08-09 Show the whole Nubble scene, and add per-pixel surface detail
    Two changes to the Android viewer.
    Full scene. The P4 shows sky and water only because it prints the island,
    rocks and lighthouse as physical relief. The framed-phone build renders
    the whole photograph instead -- the base is now source-cropped (the full
    registered image, not the sky+water plate) and a land mask (island union
    foreground, bit-packed) marks the solid parts. Those pixels are drawn
    untouched: no grading, no waves, no detail. They are a placeholder for the
    3D-printed relief that will cover them, so what shows on screen is exactly
    what the print replaces, correctly registered. The island and lighthouse
    rise above the ho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
2026-08-09 Make the sky live: on-device solar, refraction-correct, continuous
    The sky was static -- a one-shot scene fetch at launch, no clock, and on
    the test device the fetch failed anyway. Now it tracks the real day.
    Solar position is computed on-device (NOAA algorithm) for Cape Neddick
    from the system clock, so the sky grades through dawn, day, golden hour,
    the three twilights and night with no network at all -- the same thing the
    P4 does by computing York's position locally. Validated on the host
    against the solstices and equinox (70.27 / 46.56 / 23.39 deg peak
    altitude, all within 0.2 deg of the geometric expectation). Atmospheric
    refraction is applied because the whole point is accuracy: it lif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
2026-08-09 Use a sharper Nubble photo, registered to the validated frame
    Swaps the base photograph for a newer, higher-resolution Sohier Park shot
    of Nubble. Rather than re-fit the camera to it -- fragile, and the source
    of the earlier tilt and scale errors -- the new photo is warped into the
    original scene's already-validated registration.
    The transform is an ORB feature match between the two photographs
    (masked to the island so sky and water, which differ between shots, do
    not pollute it), reduced to scale + translation with zero rotation so the
    lighthouse stays vertical. 374 RANSAC inliers at 4.3 px RMS, and a 50/50
    blend confirms the island, structures, horizon and foreground rocks all
    register. B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
2026-08-09 Fix render-thread crash on screen sleep/wake
    "Unfortunately Luminary has stopped" was a native SIGSEGV in
    lum_render_frame: the render thread writes into the ANativeWindow buffer
    while surfaceDestroyed (screen sleep, app backgrounded) released that
    window on the UI thread -- a use-after-free. A wall display sleeps and
    wakes, so this had to be solid.
    Guard the window pointer with a mutex: nativeSetSurface holds it while
    releasing/replacing the window, and nativeRenderFrame holds it across the
    whole lock/render/unlock so the window cannot be freed mid-frame.
    Stress-tested with repeated screen off/on -- previously a reliable crash,
    now zero.
    Also confirmed while debugging: the sky is genuinel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
2026-08-09 Plain sky with the three satellite cloud layers over it
    Per the brief -- plain sky, clouds overlaid from satellite -- the base
    photo's own sky is replaced with a clean clear-sky gradient (sampled from
    the photograph's own blue so the light matches), keeping the island,
    lighthouse, rocks and animated sea. The three GOES-derived cloud shells
    (low/mid/high) then composite over that plain sky and drift on the
    measured winds, which the previous baked-in photo sky prevented.
    This uses the cloud atlases currently bundled in the APK, so the layers
    are satellite-derived but not yet refreshed live. Wiring the per-poll
    download of fresh atlases (so the sky matches the sky over Nubble right
    now) is the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
2026-08-09 Luminary Android: live GOES clouds, high-res atlas, seam fixes, validation
    Rendering (android/.../luminary_render_core.c):
    - Detail-shimmer scroll now oriented by the live swell from_deg (shoreward +
    alongshore mapped through the camera), replacing fixed vectors, so the surface
    drifts with real conditions. Verified host-side across from_deg 45/90/137/200.
    - Water tiling removed: 256px detail-field retuned to fine shimmer; solver-grid
    bilinear faceting smoothstepped (C1); X-gradient refraction bilerped.
    - Cloud atlas sampled bilinear + per-pixel (was nearest / 4px quad steps),
    edges mirror-folded and softened at load.
    - CFD_SHADE_GAIN knob (kept at 24; boosting it re-exposed near-fiel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
2026-08-10 PWA at /app: Luminary live in the browser via WebAssembly
    Compiles the SAME portable C core (luminary_render_core.c + ocean_sim.c) to
    WebAssembly and drives a canvas, so the browser renders bit-identical water and
    sky to the Android app and P4 firmware -- one source of truth.
    - tools/wasm/luminary_wasm.c: single-threaded wasm entry (init/tick/render/
    set_conditions/set_clouds); the core's RGBX8888 output is already canvas
    ImageData layout, so frames blit with no swizzle. Single-threaded because
    GitHub Pages sends no COOP/COEP, so SharedArrayBuffer/pthreads are out; the
    core's mutexes resolve to Emscripten no-op stubs.
    - scripts/build-pwa.sh: emcc build + asset copy into site/app (Pa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
